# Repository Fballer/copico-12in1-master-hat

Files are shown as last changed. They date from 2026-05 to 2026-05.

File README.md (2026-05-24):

# Copico 12-in-1 Master Hat

The **Copico 12-in-1 Master Hat** is the ultimate expansion for the Tandy Color Computer. It emulates 12 legendary pieces of CoCo hardware using the high-performance Raspberry Pi RP2350 and an ESP32-C3 for wireless connectivity.

## 🚀 Emulated Hardware Features
1.  **Orchestra-90 CC**: 8-bit Stereo Audio.
2.  **Speech & Sound Pak**: PSG sound with automatic CoCo 3 pitch correction.
3.  **RS-232 Pak**: ACIA serial communication.
4.  **WordPak 2+**: MSX2+ (V9958) 80-column VGA graphics.
5.  **CoCoSDC**: High-speed MicroSD storage and disk emulation.
6.  **WiModem**: AT-command compatible wireless modem.
7.  **DriveWire 4**: Wireless virtual serial disk streaming.
8.  **FujiNet**: Cloud-based sector streaming and network tools.
9.  **Real-Time Clock**: DS3231-based system clock.
10. **SuperSprite FM+**: TMS9918 video + OPL2 FM synthesis sound.
11. **CoPico X-BIOS**: Software-based personality swapping via Native VDG menu.

## 📂 Repository Structure
*   `firmware/`: Source code for RP2350 (PIO-based bus trapping) and ESP32-C3.
*   `docs/`: Schematic, pin map, assembly guide, firmware roadmap.
*   `references/`: Technical specifications for the emulated hardware.

> **Developing locally:** Open [`copico.code-workspace`](copico.code-workspace) (includes `lwtools-4.21` + `copico-bonobo-main` siblings). See [Project ecosystem](docs/ecosystem.md).

## 🛠 Documentation
*   [Project ecosystem & workspace setup](docs/ecosystem.md)
*   [Hat schematic (verified wiring)](docs/schematic_copico10in1-fixed_2026-05-24.png)
*   [GPIO pin map](docs/pinmap.md)
*   [Hardware Build Guide](docs/build_guide.md)
*   [Firmware Architecture Plan](docs/firmware_plan.md)
*   [User Guide](docs/user_guide.md)

---
*Created with AntiGravity - May 2026*

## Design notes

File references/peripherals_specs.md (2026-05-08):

# Peripheral Technical Summary: Orchestra-90 and 6551 ACIA

## 1. Orchestra-90 (Sound Pak)
The Orch-90 is a dual 8-bit DAC system. It is extremely simple to emulate.
*   **$FF7A**: Left Channel DAC (Write 8-bit signed/unsigned byte).
*   **$FF7B**: Right Channel DAC (Write 8-bit signed/unsigned byte).
*   **Sampling**: There is no hardware timer. The CoCo CPU manually POKEs values to these ports to create waveforms. 
*   **RP2350 Implementation**: We trap the write to $FF7A/B and immediately push the value to the I2S DMA buffer.

---

## 2. 6551 ACIA (RS-232 Pak)
The ACIA is the standard serial controller for the CoCo. It is mapped to **$FF68-$FF6B**.

| Address | Register | Function |
| :--- | :--- | :--- |
| **$FF68** | **Data** | Read (Rx) / Write (Tx) serial data. |
| **$FF69** | **Status** | Read IRQ, Overrun, Framing Error, Tx/Rx buffer status. |
| **$FF6A** | **Command** | Control parity, interrupts, and DTR/RTS lines. |
| **$FF6B** | **Control** | Set Baud Rate (50 to 19200 bps), word length, and stop bits. |

### **Status Register Bits ($FF69 Read)**
*   **Bit 0 (IRQ)**: 1 = Interrupt has occurred.
*   **Bit 3 (Rx Full)**: 1 = Data received and ready to read from $FF68.
*   **Bit 4 (Tx Empty)**: 1 = Ready to accept new data for transmission.
*   **Bit 5 (DCD)**: Data Carrier Detect status.
*   **Bit 6 (DSR)**: Data Set Ready status.

### **Control Register Bits ($FF6B Write)**
*   **Bits 0-3**: Baud rate selection.
    *   `1110`: 9600 bps
    *   `1111`: 19200 bps
*   **Bits 5-6**: Word length (8, 7, 6, 5 bits).
*   **Bit 7**: Stop bits (1 or 2).

### **RP2350 Implementation**
The RP2350 will bridge these register writes to its internal **Hardware UART0** (connected to the MAX3232 module) or to the **ESP32-C3** for virtual WiModem functionality.

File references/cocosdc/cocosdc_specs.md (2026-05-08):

# CoCoSDC Technical Summary (Emulation Specifications)

## 1. Memory-Mapped Registers ($FF40 - $FF4B)
The CoCoSDC emulates a standard FDC at $FF40-$FF47 but uses $FF48-$FF4B for "Extended SDC Mode" operations.

| Address | Function (Extended Mode) |
| :--- | :--- |
| **$FF40** | **Control Register**: Write `$43` to activate Extended SDC Mode. |
| **$FF48** | **Command/Status**: Write commands (Read, Write, Mount); Read status bits. |
| **$FF49** | **LSN High**: Bits 16-23 of the 24-bit Logical Sector Number. |
| **$FF4A** | **LSN Mid / Data Port 1**: Bits 8-15 of LSN / 8-bit data transfer port. |
| **$FF4B** | **LSN Low / Data Port 2**: Bits 0-7 of LSN / 8-bit data transfer port. |

## 2. Status Register Bits ($FF48 Read)
*   **Bit 0 (BUSY)**: 1 = Controller is busy. Wait for 0 before sending a new command.
*   **Bit 1 (READY)**: 1 = Data is ready in the buffer (for Reads) or buffer is ready (for Writes).
*   **Bit 7 (ERROR)**: 1 = Operation failed.

## 3. Command Set ($FF48 Write)
*   **$80**: Read 256-byte sector from current LSN.
*   **$A0**: Write 256-byte sector to current LSN.
*   **$E0**: Mount Drive 0. Requires sending a 256-byte packet with the filename string.
*   **$E1**: Mount Drive 1.

## 4. Block Transfer Protocol
1.  Set the 24-bit LSN using $FF49, $FF4A, $FF4B.
2.  Issue command $80 or $A0.
3.  Wait for Bit 1 of $FF48 to go high.
4.  Transfer 256 bytes by alternating reads/writes between **$FF4A** and **$FF4B**. 
    *   *Note: In RP2350 emulation, we can detect the alternating access to handle the byte streaming from the internal SD buffer.*

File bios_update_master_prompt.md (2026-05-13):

# Master Task: Finalizing the CoPico X-BIOS (formerly Chameleon)

## 🎯 Objective
Update the 6809 assembly-based BIOS for the **Copico 12-in-1 Master Hat (RP2350 + ESP32-C3)**. The goal is to implement a robust "Setup Required" alert system for missing ROMs and a "Utility Page" for managing the new Flash ROM Bank architecture.

---

## 🏗️ System Architecture
- **Master Controller**: RP2350 (ARM Cortex-M33 @ 150MHz).
- **Coprocessor**: ESP32-C3 (Handles WiFi, SD Card, and Bluetooth).
- **Host**: Tandy Color Computer (CoCo) 1, 2, or 3.
- **Interconnect**:
    - **RP2350 <-> CoCo**: Parallel bus sniffer via PIO (Address: G32-G47, Data: G0-G7).
    - **RP2350 <-> ESP32**: High-speed SPI (G23/G24/G30/G31).
    - **Video**: 640x480 VGA (PIO/DMA driven).

---

## 💾 Flash ROM Bank Layout (256KB @ 0x3C0000)
The RP2350 uses its internal flash to store ROM images in 16KB slots.
- **Slot 0**: CoPico X-BIOS (Pre-loaded).
- **Slot 1**: SDC-DOS (Auto-installed from SD card).
- **Slot 2**: FujiNet BIOS (Pre-loaded/Downloadable).
- **Slot 3**: RS-232 Pak ROM (Pre-loaded).
- **Banks 0-7**: CoCoSDC Array (Bank 1 is pre-loaded with Disk BASIC 1.1).

---

## 🖥️ Shared Memory Interface ($C000 - $DFFF)
The BIOS runs in the CoCo's address space. The RP2350 serves data to the BIOS and monitors its state via specific memory addresses:
- **$C000 - $D7FF**: Main BIOS Binary (8KB).
- **$D800 - $D81F**: WiFi Status String (from ESP32).
- **$D820 - $D83F**: Firmware Version String.
- **$D840 - $D85F**: SD Card Status String.
- **$D880**: **FLASH_STATUS_BYTE** (Bit 0: 1=SDC-DOS Missing, 0=OK).
- **$FF70 - $FF73**: Hardware Config Registers (Audio, Video, Disk, Comm).
- **$FF74**: **MODE_SWITCH_CMD** (Write a mode ID here to trigger a hardware swap).

---

## ⚡ Hardware Pinout (Verified PCB Netlist)
- **PIN_BTN_DUAL (G19)**: Held at boot forces CoPico X-BIOS (Slot 0).
- **PIN_STATUS_LED (G17)**: System status.
- **VGA Sync**: H-Sync (G26), V-Sync (G27).
- **VGA RGB**: G18, G22, G28 (mapped via PIO).
- **I2S DAC**: BCK (G10), DIN (G11), LCK (G12).

---

## 🛠️ BIOS Requirements (6809 Assembly)
1. **Name Change**: Rename all UI labels and internal strings to **CoPico X-BIOS**.
2. **Startup Alert**: On boot, check `$D880`. If Bit 0 is set, display a large, detailed "SETUP REQUIRED" screen.
    - Message: "Please place COCOSDC.ROM in /ROMS/ folder on SD card and restart to install SDC-DOS."
3. **ROM Utility Page**:
    - Add a new menu page: `Flash ROM Management`.
    - Options: `Scan SD for ROMs`, `Clear Flash Bank`, `Re-install Defaults`.
4. **Hardware Pass-through**: Implement an option for `MODE_INTERNAL_ROM` which tri-states the Hat and lets the CoCo boot its internal ROMs.

---

## 📂 Current Progress
- C++ Flash Manager is complete and pushed to `phase8-rtc`.
- SPI timeouts and Jitter-free VGA are implemented.
- `switch_mode()` now handles 16KB flash loads and tri-state recovery.
- Project renamed to **CoPico X-BIOS**.

**Please begin by reviewing `firmware/master-hat-firmware/bios/xbios.asm` and proposing the UI update plan.**

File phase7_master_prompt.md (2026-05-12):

# Copico 12-in-1 Master Hat: Phase 7 (Wireless Suite) Master Prompt

## Role & Context
You are Antigravity, an expert embedded C++ AI coding assistant. We are building the firmware for the **Copico 12-in-1 Master Hat**, an expansion system for the vintage Tandy Color Computer (CoCo). 

We are starting **Phase 7: Wireless Suite**. To save tokens, we are beginning a fresh conversation. You must assimilate the following architecture, constraints, and progress to continue seamlessly.

## System Architecture
The system utilizes a dual-processor architecture:
1.  **Host Processor**: Raspberry Pi RP2350.
    *   **Core 1**: Runs a hyper-critical PIO bus sniffer (`coco_bus.pio`). It listens to the CoCo's 6809 CPU and must respond within **<500ns**. *Rule: Never introduce blocking delays, Mutexes, or heavy computation on Core 1.*
    *   **Core 0**: Handles the main loop, peripheral emulation (`tick()` functions), and I2S/VGA DMA management.
2.  **Network Coprocessor**: ESP32-C3. 
    *   Dedicated to handling TCP/IP, WiFi, Telnet, and FAT32 SD Card operations.

### The Interconnect (SPI)
The RP2350 and ESP32-C3 communicate exclusively over SPI. 
*   **RP2350 Pins**: `MISO` (23), `MOSI` (24), `CS` (26), `SCK` (28).
*   **Protocol**: Defined in `lib/shared/spi_protocol.h`. It relies on a fixed 264-byte packet (`SpiMasterPacket` / `SpiSlavePacket`) padded with a sync byte (0xAA) and a checksum.
*   **Current State**: We currently have two classes trying to use SPI: `Esp32Bridge` (synchronous, blocking polling used for SD card reads) and `SpiStream` (asynchronous, non-blocking tick-based stream meant for WiModem serial). *They currently share the same pins and need unification/careful management.*

## Current Project State (Phases 1-6 Complete)
*   **Chameleon BIOS**: We have completely written a 6809 assembly BIOS (`bios/chameleon.asm`) that lives in the RP2350 and gets injected into the CoCo's ROM space at `$C000-$DFFF`. It provides a native 32x16 UI to dynamically swap emulator modes (e.g., `MODE_WIMODEM`, `MODE_COCOSDC`, `MODE_ORCH90`).
*   **Shared BIOS Memory**: The BIOS reads real-time status strings from the RP2350 at specific memory addresses:
    *   `$C800`: WiFi Status String
    *   `$C820`: ESP32 Firmware Version String
    *   `$C840`: SD Card Status String
*   **Emulators Built**: We have functioning classes for `Acia6551` (RS-232), `Pic7040`/`Ay8913`/`Spo256` (Speech/Sound), `V9958` (VGA), and `Cocosdc` (SD floppy).

## Phase 7 Goals
The objective of Phase 7 is to bring the ESP32-C3 online and implement the **WiModem** (an RS-232 to Telnet bridge for BBSing).

### 1. The ESP32 Firmware (New Project)
You will need to help scaffold a brand new PlatformIO project for the ESP32-C3.
*   **Project Location**: Create the new project in `firmware/esp32-coprocessor`.
*   **Environment**: Use `board = esp32-c3-devkitm-1` (or equivalent C3 board) and `framework = arduino`.
*   **Reference**: We are NOT building the modem from scratch. You must reference the local project at `/Users/macbook/Documents/PlatformIO/Projects/New_Porta_Serial_esp32c3`. This contains a working implementation of `Zimodem` (an industry-standard AT command parser) previously built for the CoCo.
*   **Adaptation**: We must strip out the hardware UART dependencies in the `Zimodem` reference and pipe its I/O through our SPI Slave interface (`ESP32SPISlave` library) using the fixed 264-byte packets.

### 2. The RP2350 Firmware (Existing Project)
*   **Existing ACIA Work**: We have already completed the `Acia6551` class (during Phase 3). While it is pending final hardware verification, it supports both Legacy and Turbo modes (up to 115200 baud) and is designed to accept ANY Arduino `Stream` via dependency injection. **Do NOT rebuild or modify `acia6551.cpp` for no reason**.
*   **Bridging**: In `main.cpp`, the physical RS-232 Pak uses `Acia6551 acia(&rs232_serial);`. For the WiModem, we have already wired up `Acia6551 wimodem(&spi_wimodem_stream);`. When `current_mode == MODE_WIMODEM`, Core 1 successfully routes `$FF68-$FF6B` register access to this `wimodem` object.
*   **SpiStream**: Because `wimodem` takes the `SpiStream` pointer, your only task on the RP2350 side is to finalize `spi_stream.cpp`. You must ensure that bytes written to the ACIA are pushed into the SPI TX ring buffer, and then flushed to the ESP32 via our 264-byte SPI packets during Core 0's 5ms `tick()` cycle.

## Your Immediate Instructions
1. Acknowledge this context and confirm your understanding of the architecture.
2. Draft a step-by-step Execution Plan for Phase 7 based on this prompt. 
3. Stop and wait for my approval before modifying any files or executing terminal commands.

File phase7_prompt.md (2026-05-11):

# Phase 7: Wireless Suite (ESP32-C3) - AI Prompt

**Role:** You are Antigravity, an expert embedded C++ AI coding assistant. We are building the firmware for the Copico 12-in-1 Master Hat, an expansion system for the Tandy Color Computer (CoCo) that uses an RP2350 (Host) and an ESP32-C3 (Network Coprocessor).

**Objective:** Begin Phase 7 (Wireless Suite). The goal is to integrate the ESP32-C3 over SPI to provide the CoCo with WiFi, a WiModem (RS-232 to Telnet bridge), DriveWire/FujiNet network disk streaming, and Cloud CoCoSDC capabilities.

### System Context & Constraints (Phases 1-6 Completed)
You are building on top of a highly integrated, stable codebase. You must ensure new code does not break existing functionality.
1.  **Architecture**: Dual-Core RP2350. Core 1 runs a time-critical PIO bus sniffer (`coco_bus.pio`) that responds to the 6809 CPU in <500ns. Core 0 handles high-level emulation loops (`tick()` functions).
2.  **Current Modes**: We have successfully implemented `MODE_ORCH90`, `MODE_SPEECH_SOUND`, `MODE_RS232_PAK_LEGACY`/`TURBO`, `MODE_WORDPAK2` (VGA), and `MODE_COCOSDC` (SD Card FAT32).
3.  **Hardware Resources (CRITICAL)**:
    *   **PIO0**: 2 SMs used by the Bus Sniffer.
    *   **PIO1**: 3 SMs used by the VGA Driver.
    *   **DMA**: VGA and I2S audio use active DMA channels.
    *   *Do NOT reallocate these resources or introduce blocking delays in Core 1.*
4.  **ESP32-C3 Hardware Mapping**:
    *   The ESP32 communicates with the RP2350 via SPI on these RP2350 pins: `MISO` (G23), `MOSI` (G24), `CS` (G26), `SCK` (G28).

### Phase 7 Requirements & Strategy
1.  **Do NOT Build From Scratch**: Leverage existing open-source projects to save time and ensure stability.
    *   **WiModem (7B)**: Reference `Zimodem` (boisy/Zimodem) or `GuruModem` for handling AT commands and Telnet bridging.
        *   **CRITICAL REFERENCE**: Use the local project [New_Porta_Serial_esp32c3](file:///Users/macbook/Documents/PlatformIO/Projects/New_Porta_Serial_esp32c3) as a primary guide. It contains a working WiModem setup previously built for the CoCo using the same ESP32-C3 processor.
    *   **Network Drives (7C/7D)**: Reference the `FujiNet` firmware stack (FujiNetWIFI) for SPI-to-Network bridging, or `pyDriveWire` specs for the DriveWire protocol.
2.  **Dual-Firmware Architecture**: We will need to write/adapt firmware for **both** the RP2350 (to marshal data between the CoCo bus and SPI) and the ESP32-C3 (to handle the TCP/IP stack and AT commands).
3.  **Integration**: The RP2350 logic must fit into our existing "Chameleon" architecture. For example, when `current_mode = MODE_WIMODEM`, Core 1 should trap the ACIA 6551 registers (like in Phase 3) but route the data to the ESP32 via SPI instead of a local hardware UART.

### Your First Task:
1.  Analyze this prompt and the current state of the workspace (specifically `main.cpp` and `docs/firmware_plan.md`).
2.  Do NOT write C++ code yet. 
3.  Draft a detailed `implementation_plan.md` for Phase 7. 
    *   Outline the SPI communication protocol we will use between the RP2350 and ESP32.
    *   Specify which open-source libraries we will pull in for the ESP32 firmware.
    *   Detail how we will bridge the existing `Acia6551` class to the new WiFi modem.
4.  Stop and wait for my approval before modifying source files.

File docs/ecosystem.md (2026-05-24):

# CoPico project ecosystem

This repo (`copico-12in1-master-hat`) is the **shipping firmware** for the PortaCoco 10-in-1 Centipede 32z hat. It sits inside a larger folder on disk that you should open as one workspace when developing.

## Recommended Cursor / IDE workspace

**Option A (best):** Open `copico.code-workspace` in this repo — it includes this firmware, `lwtools-4.21`, and `copico-bonobo-main` as multi-root folders. Bonobo KiCad/Gerbers are excluded from search/index via `copico-bonobo-main/.cursorignore` and workspace `search.exclude` (keeps `centipede-watcher/`, `references/`, and `.md` files).

**Option B:** Open the parent folder:

```
/Users/macbook/Documents/PlatformIO/Projects/copico/
```

That gives agents and search access to build tools and reference material without copying them into git.

## Sibling folders (under `copico/`)

| Path | Purpose |
|---|---|
| **`copico-12in1-master-hat/`** (this repo) | RP2350 + ESP32 firmware, docs, `references/` |
| **`lwtools-4.21/`** | 6809 assembler (`lwasm`) for CoPico X-BIOS — used by `firmware/master-hat-firmware/bios/build_bios.py` |
| **`copico-bonobo-main/`** | Centipede 32z/32d KiCad, `centipede-watcher` bus-sniffer experiments, extra `hat-fuji-40c/references/` |
| **`hardware/`** | Production Gerbers, schematic PDFs, PCB archives (not source of truth for day-to-day wiring) |

## Authoritative hardware docs (this repo)

| Doc | Use |
|-----|-----|
| [schematic_copico10in1-fixed_2026-05-24.png](schematic_copico10in1-fixed_2026-05-24.png) | **Wiring you built** — PortaCoco 10-in-1 hat (rev 2.12) |
| [pinmap.md](pinmap.md) | GPIO ↔ net names ↔ firmware `#define`s |
| [build_guide.md](build_guide.md) | Assembly BOM and J3/J4 steps (verified section only) |

Ignore `hardware/` in this repo (excluded via `.cursorignore`) — old FujiNet-era KiCad, not the Centipede hat you assembled. Use `docs/schematic_copico10in1-fixed_2026-05-24.png` instead.

## Build commands

```bash
# RP2350 (default)
cd firmware/master-hat-firmware && pio run -e rp2350

# ESP32 coprocessor (from same project)
pio run -e esp32c3_coprocessor

# CoPico X-BIOS ROM (needs lwasm — see lwtools-4.21 sibling)
cd firmware/master-hat-firmware/bios && python3 build_bios.py
```

## Centipede base board (CoCo bus)

The hat schematic covers J3/J4 peripherals. The **6809 bus** pins are on the Centipede 32z itself:

| CoCo signal | RP2350 GPIO | Firmware |
|---|---|---|
| D0–D7 | 0–7 | `coco_bus.pio` |
| A0–A15 | 32–47 | `coco_bus.pio` |
| R/W | 20 | `PIN_RW`, PIO jmp pin |
| E-clock | 21 | `PIN_E_CLOCK` |

See `copico-bonobo-main/v3.1-centipede/README.md` for the full Centipede pin table (Q, NMI, RESET, etc.).

## Git

Only `copico-12in1-master-hat` is a git repository. Siblings are local support files — do not expect them on GitHub clones unless you copy `lwtools-4.21` yourself or install `lwasm` on PATH.

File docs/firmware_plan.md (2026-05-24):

# Copico 12-in-1 Master Hat: Firmware Architecture & Implementation Plan
**Date: May 2026 — Updated with verified PCB netlist (Hat-Fuji-40C v1)**

This document details the software architecture and development roadmap for the **12-in-1 Master Hat**. It leverages the RP2350 dual-core processor to emulate an entire suite of CoCo expansions.

> [!IMPORTANT]
> This plan assumes the hardware is built according to the [Hardware Assembly Guide](build_guide.md) and [pin map](pinmap.md) (see [schematic](schematic_copico10in1-fixed_2026-05-24.png)).

## 1. System Philosophy: The "CoPico X-BIOS" Expansion
The RP2350 acts as a real-time bridge between the CoCo's 6809 bus and modern peripherals. By dynamically swapping PIO state machines and memory maps, a single physical board becomes 12 different classic cartridges.

> [!IMPORTANT]
> **LOCAL SPECIFICATIONS FIRST**: The technical "guts" (registers, ports, and protocols) for these modules have been saved directly to this project. **Reference these local files first** during the firmware build to ensure we stay offline and fast.

| Emulation Mode | Core Hardware | Technical Reference / Repository |
| :--- | :--- | :--- |
| **Orchestra-90** | 8-bit Mono DAC | [Archive: Orch-90 Manual](https://colorcomputerarchive.com/repo/Documents/Manuals/Hardware/Orchestra-90%20(Tandy).pdf) \| **[LOCAL: Peripherals Specs](../references/peripherals_specs.md)** |
| **Speech & Sound** | AY-3-8910 (PSG) | [GitHub: AY-3-8910 Emulation](https://github.com/mamedev/mame/blob/master/src/devices/sound/ay8910.cpp) \| [GitHub: LibAYemu](https://github.com/vsergeev/libayemu) |
| **RS-232 Pak** | ACIA 6551 | [Reference: 6551 Datasheet](https://www.westerndesigncenter.com/wdc/documentation/w65c51n.pdf) \| **[LOCAL: Peripherals Specs](../references/peripherals_specs.md)** |
| **WordPak 2+** | Yamaha V9958 | [Source: CoCoLoCo WordPak-2](https://sites.google.com/site/tandycocoloco/wordpak-2) \| **[LOCAL: V9958 Specs](../references/wordpak2/v9958_specs.md)** |
| **CoCoSDC** | Custom FDC | [Blog: CoCoSDC Official](http://cocosdc.blogspot.com/) \| **[LOCAL: CoCoSDC Specs](../references/cocosdc/cocosdc_specs.md)** |
| **FujiNet** | ESP32 Networking | [GitHub: FujiNet PlatformIO](https://github.com/FujiNetWIFI/fujinet-platformio) \| [GitHub: fujinet-firmware](https://github.com/FujiNetWIFI/fujinet-firmware) |
| **DriveWire 4** | Virtual Serial Disk | [Source: DriveWire 4](http://www.drivewire4.com/) \| [GitHub: pyDriveWire](https://github.com/n64764/pyDriveWire) |
| **WiModem** | AT Command Modem | [Reference: Zimodem Firmware](https://github.com/boisy/Zimodem) \| [GitHub: GuruModem](https://github.com/pizet/GuruModem) |
| **Real-Time Clock** | MSM5832 Emulation | [Library: DS3231 I2C](https://github.com/adafruit/Adafruit_DS3231) \| [GitHub: CoCo RTC Driver](https://github.com/boisy/NitrOS-9/blob/master/sys/modules/rtc3231.as) |
| **SuperSprite FM+** | TMS9918 + OPL2 | [Reference: TMS9918 Datasheet](https://www.msxarchive.nl/pub/msx/mirrors/hansa.xs4all.nl/tms9918.pdf) \| [GitHub: OPL2 Emulator](https://github.com/D-S-X/OPL2-Emulation) |
| **CoPico X-BIOS** | Injected 6809 Code | [Source: FujiNet Config Application](https://github.com/FujiNetWIFI/fujinet-config) \| [GitHub: Mega-Cart](https://github.com/sublogic/MegaCart) |

---

## 3. Development Roadmap & Success Probability

We will develop each module in isolation, hardcoding the RP2350 for testing before integrating them into the master Boot Menu.

### Phase 1: Orchestra-90 Emulation (Success: 95%)
*   Trap `$FF7A/B` and push to I2S DAC. Simple bus-sniffing "quick win."

### Phase 2: Speech and Sound Pak (Success: 85%)
*   Real-time synthesis of PSG waveforms in the RP2350 CPU core.
*   **CoCo 3 / 6309 / GIME-X Auto-Correction**: Detect host E-Clock frequency in real-time (0.89MHz to 3MHz+). Normalizes PSG pitch and ensures bus-trapping logic remains stable during high-speed operation.

### Phase 3: RS-232 Pak (Success: 90%)
*   Emulate ACIA registers and route to physical MAX3232 pins.

### Phase 4: WordPak 2+ (V9958 VGA) (Success: 75%)
*   **The "Boss Fight"**: Emulate MSX2+ graphics and output 3-bit RGB VGA. Requires intense PIO optimization. Master this first to provide the video foundation for the SuperSprite.

### Phase 5: The Native Boot Menu (Success: 85%)
*   Inject 6809 assembly into CoCo RAM to display a selection menu on the native screen.

### Phase 6: CoCoSDC (Local Storage) (Success: 80%)
*   Implement FAT32 support and precise floppy controller timing.

### Phase 7: Wireless Suite (ESP32-C3)
*   **7A. WiFi Connection** (95%)
*   **7B. Wireless WiModem** (90%): Bridge RS-232 to Telnet via ESP32.
*   **7C. FujiNet / DriveWire** (80%): Stream sectors over the local network.
*   **7D. Cloud CoCoSDC** (75%): Fetch `.DSK` files directly from the Color Computer Archive.

### Phase 8: SuperSprite FM+ (Success: 70%)
*   **Advanced Feature**: Leverage the V9958 VGA core from Phase 4 and add software FM synthesis (OPL2 emulation). This turns the CoCo into an FM-synth music machine.

---

## 4. Boot Menu & ROM Management
*   **Native VDG Menu**: The primary menu runs on the CoCo's original green/black screen.
*   **BIOS Shared Memory**: The RP2350 exposes a shared memory block starting at `$D800` for the 6809 to read real-time status strings dynamically injected by the ESP32 and RP2350:
    *   `$D800`: WiFi Status (max 32 bytes, null-terminated)
    *   `$D820`: ESP32 Firmware Version (max 32 bytes, null-terminated)
    *   `$D840`: SD Card Status (max 32 bytes, null-terminated)
    *   `$D860`: Time Zone Setting (max 32 bytes, null-terminated)

> [!NOTE]
> Status buffers were relocated from `$C800` to `$D800` (Phase 8) to prevent conflicts with the BIOS ROM code space (`$C000-$DFFF`).

*   **Hardware Registers**:
    *   `$FF50-$FF51`: Emulated MSM5832 RTC interface (compatible with Disto 4-N-1 and NitrOS-9).
    *   `$FF70`: Boot Menu Audio selection register.
    *   `$FF71`: Boot Menu Video selection register.
    *   `$FF72`: Boot Menu Disk selection register.
    *   `$FF73`: Boot Menu Comm selection register.
    *   `$FF75`: Time Zone index register (Write 0-17 to select timezone; ESP32 applies POSIX TZ string).
    *   `$FF7F`: Mode-switch register (Write EmulatorMode value to switch; Write `$55` from Boot Menu to save+switch).

*   **RP2350 ↔ ESP32 SPI Link (Verified PCB Netlist)**:
    *   **CS** : RP2350 **G23** ↔ ESP32 **GPIO4** (J4 Pin 7)
    *   **MISO**: RP2350 **G24** ↔ ESP32 **GPIO0** (J4 Pin 9)
    *   **SCK** : RP2350 **G30** ↔ ESP32 **GPIO3** (J4 Pin 15)
    *   **MOSI**: RP2350 **G31** ↔ ESP32 **GPIO1** (J4 Pin 16)
*   **Personality Swapping**: Selecting a menu item triggers a "hot-swap" of the RP2350's memory mapping.

### ROM Management Strategy (16KB Flash Bank Architecture)
The CoPico X-BIOS leverages a robust 256KB flash bank (12 slots of 16KB) for instant-on performance and hardware-accurate bank switching:

1.  **Slot 0: CoPico X-BIOS**: (Embedded). The system's primary control menu.
2.  **Slot 1: SDC-DOS**: (Auto-installed). Required for CoCoSDC disk emulation. Installed from SD card on first boot to maintain legal compliance.
3.  **Slot 2: FujiNet BIOS**: (Embedded). Networking ROM for the ESP32 bridge.
4.  **Slot 3: RS-232 Pak ROM**: (Embedded). Deluxe RS-232 ROM for terminal communication.
5.  **Slots 4-11: CoCoSDC Banks**: Emulates the 8-bank hardware array. Bank 0 (Slot 4) defaults to SDC-DOS; Bank 1 (Slot 5) defaults to Disk BASIC 1.1.

*   **Recovery Mode**: Powering on while holding **G19** (Dual Button) forces an immediate bypass to the CoPico X-BIOS (Slot 0), allowing recovery from a soft-bricked state.
*   **Bank Switching**: Responds to `RUN @n` commands via the PIO bus sniffer, mirroring the real CoCoSDC hardware behavior.

### Bus Timing: Hybrid Fast-Map I/O Dispatch

> [!IMPORTANT]
> The CoCo bus at **2.86 MHz** (GIME-X + 6309 turbo) gives only **175 ns** to respond to a read. The original firmware used a C++ `if/else` chain that consumed ~40 ns in branch comparisons alone. Combined with slow `gpio_set_dir_out_masked()` calls, worst-case latency was ~500 ns — a guaranteed failure at turbo speeds.

**Solution (Phase 8 Fortification):**

1.  **PIO Read-Response SM** (`coco_bus_read`): A third PIO state machine on PIO0 handles the entire GPIO turnaround (set output → drive data → wait E-clock fall → tri-state) in hardware. This replaced ~150 ns of C++ MMIO calls with a single 7 ns FIFO write (`BUS_RESPOND()` macro).

2.  **Hybrid Fast-Map**: The `if/else` dispatch chain was replaced with:
    *   **ROM Shadow** (`$C000-$DFFF`): A single function pointer (`rom_read_handler`). One comparison + one indirect call = ~20 ns.
    *   **I/O Space** (`$FF00-$FFFF`): A 256-entry function pointer table (`io_read_table[]` / `io_write_table[]`), indexed by `addr & 0xFF`. One array access + null check + indirect call = ~7 ns.
    *   Tables are rebuilt on every mode switch via `rebuild_io_tables()`.

| CoCo Speed | Budget | Estimated Latency | Margin |
| :--- | :--- | :--- | :--- |
| 1.0 MHz (Stock) | 500 ns | ~120 ns | ✅ 380 ns |
| 1.79 MHz (Turbo) | 279 ns | ~120 ns | ✅ 159 ns |
| 2.86 MHz (GIME-X) | 175 ns | ~120 ns | ✅ **55 ns** |

*   **Source files**: `io_dispatch.h`, `io_dispatch.cpp`, `coco_bus.pio` (`coco_bus_read` program).
*   **Memory cost**: 256 × 4 bytes × 2 tables = **2 KB RAM** (negligible on RP2350's 520 KB).

### VGA Jitter Elimination (DMA Interrupt-Driven Double Buffer)

> [!NOTE]
> The VGA signal is generated entirely by PIO1 (3 state machines: HSYNC, VSYNC, RGB) and fed by a DMA chain. The CPU is **never** in the VGA timing path.

**Problem**: The original `tick()` function used a blocking `while()` loop that spun until the DMA finished reading a scanline buffer. If the CPU was busy (audio synthesis, bus handling), the loop stalled, causing visible jitter.

**Solution**: A DMA completion interrupt (`DMA_IRQ_0`) fires when each scanline transfer finishes. The ISR:
1.  Atomically swaps the active buffer index (0 ↔ 1)
2.  Points the DMA at the new buffer
3.  Increments a `_scanlines_completed` counter

`tick()` checks the counter. If > 0, it renders the next scanline into the inactive buffer. If `tick()` falls behind (CPU busy), the DMA simply replays the last buffer — a graceful degradation (repeated scanline) instead of signal corruption.

*   **Source files**: `vga_driver.h`, `vga_driver.cpp`, `vga_pio.pio`
*   **ISR**: `VgaDriver::on_dma_complete()` (static, registered on `DMA_IRQ_0`)
*   **CPU impact**: Zero. VGA signal is 100% hardware-driven.

---

### Multi-Pak Interface (MPI) Compatibility
While the 10-in-1 Hat cannot connect directly to a physical floppy drive, it **can** operate inside a Tandy Multi-Pak Interface alongside a real physical Disk Controller. 
*   **Hardware Handshake**: The Hat relies on the `CTS*` (Cartridge Select) signal. When in an MPI, the MPI hardware only sends the `CTS*` signal to the currently selected slot. 
*   **Result**: The Copico will remain completely "silent" on the bus until the CoCo switches to its specific MPI slot, allowing it to perfectly co-exist with real floppy controllers or other physical cartridges without bus conflicts.

*   **Physical Override**: The SPDT switch (G20) allows forcing a "Safe Mode" boot to the menu if a firmware setting gets stuck.

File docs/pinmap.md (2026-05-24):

# GPIO pin map — verified against schematic & firmware

Source: `docs/schematic_copico10in1-fixed_2026-05-24.png` (PortaCoco 10-in-1 Centipede 32z Hat, rev 2.12) and firmware as of May 2026.

## J3 — RP2350 (2×10)

| J3 pin | Net | GPIO | Firmware |
|---|-----|---|---|
| 1 | VGA_GREEN_G8 | G8 | `vga_driver.cpp` `PIN_GREEN` |
| 5 | Sound_BCK_G10 | G10 | `main.cpp` `I2S_BCK` |
| 7 | Sound_DIN_G11 | G11 | `I2S_DIN` |
| 9 | Sound_LCK_G12 | G12 | `I2S_LCK` |
| 11 | TTL_TX_G13 | G13 | `SerialPIO` TX |
| 12 | VGA_RED_G14 | G14 | `PIN_RED` |
| 13 | TTL_RX_G15 | G15 | `SerialPIO` RX |
| 14 | VGA_VSync_G16 | G16 | `PIN_VSYNC` |
| 15 | SDC_LED_G17 | G17 | `PIN_STATUS_LED` |
| 16 | VGA_HSync_G18 | G18 | `PIN_HSYNC` |
| 17 | SDC_Button_G19 | G19 | `PIN_BTN_DUAL` |
| 18 | RESET | — | Hardware reset pad |

## J4 — RP2350 ↔ ESP32-C3 SPI

| J4 pin | Net | RP2350 | ESP32-C3 | Firmware |
|---|-----|---|---|---|
| 7 | ESP_C3_CS_G23 | G23 | GPIO4 | `esp32_bridge.cpp`, `spi_stream.cpp` |
| 9 | ESP_C3_MISO_G24 | G24 | GPIO0 | |
| 15 | ESP_C3_SCK_G30 | G30 | GPIO3 | |
| 16 | ESP_C3_MOSI_G31 | G31 | GPIO1 | |
| 10 | SND | — | — | Audio coupling (C1), not a GPIO |

## ESP32-C3 — MicroSD (CoCoSDC, not on RP2350)

| Net | ESP32 GPIO | Firmware (`main_esp32.cpp`) |
|-----|---|---|
| SDC_MOSI | 5 | `SD_MOSI` |
| SDC_MISO | 6 | `SD_MISO` |
| SDC_SCK | 7 | `SD_SCK` |
| SDC_CS | 10 | `SD_CS` |

## CoCo cartridge bus (Centipede 32z — not on hat schematic)

| Signal | GPIO | Firmware |
|---|---|---|
| D0–D7 | 0–7 | `coco_bus.pio` |
| A0–A15 | 32–47 | `coco_bus.pio` |
| R/W | 20 | `PIN_RW` |
| E-clock | 21 | `PIN_E_CLOCK` |

## Modules on schematic

| Block | Interface |
|---|---|
| PCM5102A | I2S G10–G12 → RCA (R7/R8, trimpot R9) |
| HW-044 | TTL G13/G15 → DB9 |
| VGA HD15 | RGB + sync G8, G9, G14, G16, G18 |
| ESP32-C3 Super Mini | SPI to J4; SD on GPIO 5–7, 10 |
| CoCoSDC LED / button | G17, G19 |

RTC is **software-emulated** on the RP2350 (`rtc.cpp`), synced from ESP32 NTP over SPI — no DS3231 on this schematic.

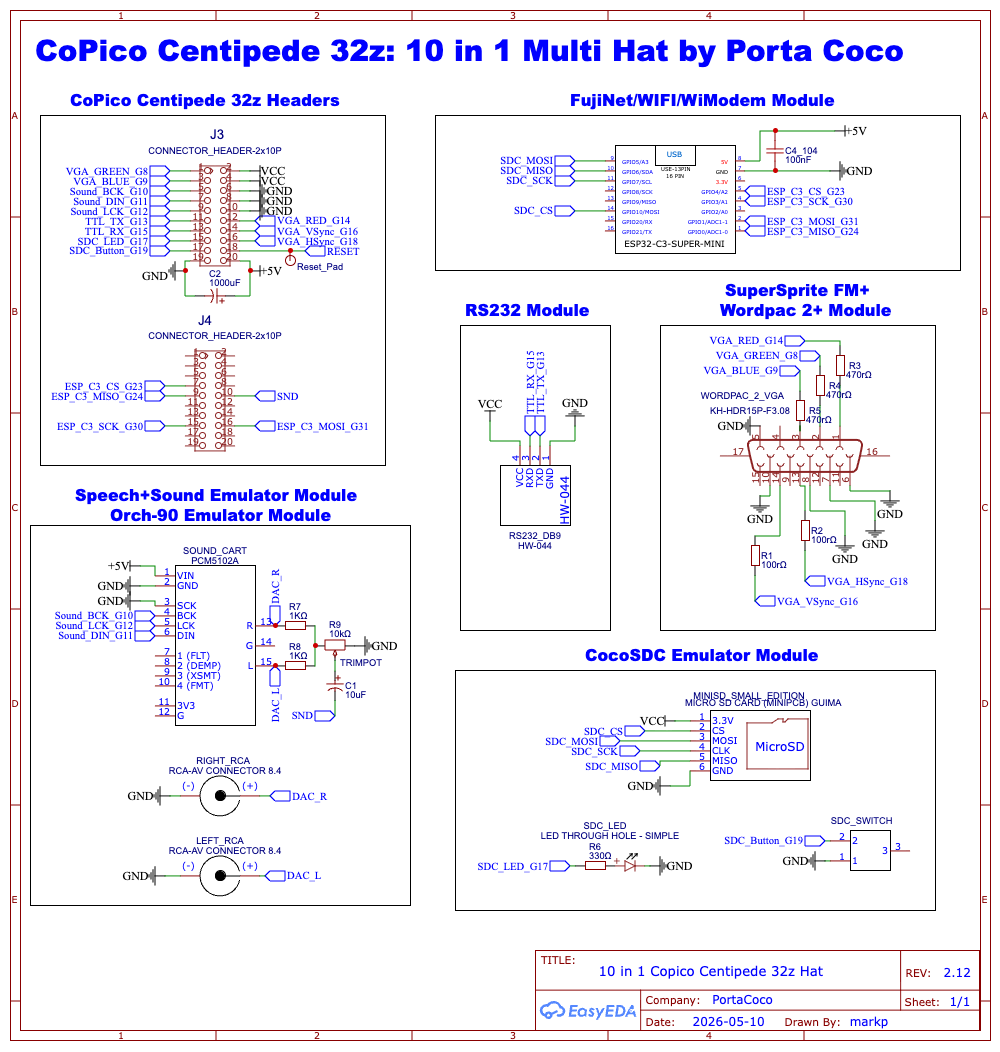
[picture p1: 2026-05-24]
docs/schematic_copico10in1-fixed_2026-05-24.png

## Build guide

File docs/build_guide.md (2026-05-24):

# Copico 12-in-1 Master Hat: Hardware Assembly Guide
**Date: May 2026 — Verified against PCB Netlist (Hat-Fuji-40C v1)**

This guide provides the complete Bill of Materials (BOM) and wiring instructions for the **12-in-1 Master Hat** built on the **Centipede 32z** board.

> [!IMPORTANT]
> This hardware is designed to work in tandem with the [Firmware Architecture Plan](./firmware_plan.md).
> Ensure all power is disconnected from the Centipede and CoCo before soldering.

> [!CAUTION]
> All GPIO assignments are **verified against** [schematic_copico10in1-fixed_2026-05-24.png](schematic_copico10in1-fixed_2026-05-24.png) (PortaCoco 10-in-1 hat, rev 2.12). See [pinmap.md](pinmap.md). An older duplicate section with wrong SD/SPI pins was removed from this file.

## Bill of Materials (BOM)

### Core Components
*   **[ ] 1x Centipede 32z Board**
*   **[ ] 2x 20-pin Female Headers (2x10, 2.54mm pitch)** (J3 and J4 slots)
*   **[ ] 1x MicroSD Card Module** (Mini PCB — GUIMA edition as per BOM)
*   **[ ] 1x PCM5102A I2S DAC Module** (Orchestra-90 / Speech+Sound output)
*   **[ ] 1x HW-044 TTL-to-RS232 Module** (MAX3232-based, DB9 connector)
*   **[ ] 1x ESP32-C3 Super Mini Module** (FujiNet / WiModem / CoCoSDC coprocessor)

### Connectors & Switches
*   **[ ] 1x HD15 Female VGA Connector** (KH-HDR15P-F3.08 footprint)
*   **[ ] 2x RCA Jacks** (Stereo audio out: LEFT_RCA, RIGHT_RCA)
*   **[ ] 1x Side-Mounted Push Button (4.5x4.5, 3-pin)** (CoCoSDC Disk Swap)
*   **[ ] 1x 5mm LED** (CoCoSDC Activity Indicator)

### Passive Components
*   **[ ] 2x 100Ω Resistors** (R1, R2 — VGA Sync lines: HSync, VSync)
*   **[ ] 3x 470Ω Resistors** (R3, R4, R5 — VGA Red, Green, Blue)
*   **[ ] 1x 330Ω Resistor** (R6 — Status LED current limiter)
*   **[ ] 2x 1kΩ Resistors** (R7, R8 — Audio DAC output mixing)
*   **[ ] 1x 10kΩ Trimpot** (R9 — Volume Control)
*   **[ ] 1x 10µF Electrolytic Capacitor** (C1 — Audio coupling/SND line)
*   **[ ] 1x 1000µF Electrolytic Capacitor** (C2 — 5V rail power stabilizer)
*   **[ ] 1x 100nF Ceramic Capacitor** (C4_104 — ESP32 3.3V noise filter)

---

## Verified GPIO Map (RP2350 Centipede 32z)

### J3 Header (2x10, 2.54mm)
| J3 Pin | Net Name | GPIO | Function |
| :--- | :--- | :--- | :--- |
| 1 | VGA_GREEN_G8 | **G8** | WordPak VGA Green -> R4 (470Ω) -> VGA Pin 2 |
| 2 | VCC | 3.3V | Power Rail |
| 3 | VGA_BLUE_G9 | **G9** | WordPak VGA Blue -> R5 (470Ω) -> VGA Pin 3 |
| 4 | VCC | 3.3V | Power Rail |
| 5 | Sound_BCK_G10 | **G10** | I2S DAC Bit Clock |
| 6 | GND | GND | Ground |
| 7 | Sound_DIN_G11 | **G11** | I2S DAC Data In |
| 8 | GND | GND | Ground |
| 9 | Sound_LCK_G12 | **G12** | I2S DAC LR Clock |
| 10 | GND | GND | Ground |
| 11 | TTL_TX_G13 | **G13** | RS-232 UART TX |
| 12 | VGA_RED_G14 | **G14** | WordPak VGA Red -> R3 (470Ω) -> VGA Pin 1 |
| 13 | TTL_RX_G15 | **G15** | RS-232 UART RX |
| 14 | VGA_VSync_G16 | **G16** | WordPak VGA VSync -> R1 (100Ω) -> VGA Pin 14 |
| 15 | SDC_LED_G17 | **G17** | Status LED -> R6 (330Ω) -> LED |
| 16 | VGA_HSync_G18 | **G18** | WordPak VGA HSync -> R2 (100Ω) -> VGA Pin 13 |
| 17 | SDC_Button_G19 | **G19** | SDC Swap Button (active LOW) |
| 18 | RESET | RESET | Hardware Reset Pad |
| 19 | GND | GND | Ground |
| 20 | +5V | 5V | Power Rail (also C2 1000µF) |

### J4 Header (2x10, 2.54mm) — ESP32 SPI Coprocessor Link
| J4 Pin | Net Name | GPIO | Function |
| :--- | :--- | :--- | :--- |
| 7 | ESP_C3_CS_G23 | **G23** | SPI CS -> ESP32 GPIO4 |
| 9 | ESP_C3_MISO_G24 | **G24** | SPI MISO <- ESP32 GPIO0 |
| 10 | SND | SND | Audio SND line (C1 coupling cap) |
| 15 | ESP_C3_SCK_G30 | **G30** | SPI SCK -> ESP32 GPIO3 |
| 16 | ESP_C3_MOSI_G31 | **G31** | SPI MOSI -> ESP32 GPIO1 |

### ESP32-C3 Super Mini GPIO Map
| ESP32 Pin | Net Name | Function |
| :--- | :--- | :--- |
| GPIO0 / ADC1-0 | ESP_C3_MISO_G24 | SPI MISO <- RP2350 G24 |
| GPIO1 / ADC1-1 | ESP_C3_MOSI_G31 | SPI MOSI -> RP2350 G31 |
| GPIO2 / A0 | (Spare) | — |
| GPIO3 / A1 | ESP_C3_SCK_G30 | SPI SCK <- RP2350 G30 |
| GPIO4 / A2 | ESP_C3_CS_G23 | SPI CS <- RP2350 G23 |
| GPIO5 / A3 | SDC_MOSI | SD Card MOSI |
| GPIO6 / SDA | SDC_MISO | SD Card MISO |
| GPIO7 / SCL | SDC_SCK | SD Card CLK |
| GPIO8 / SCK | (Internal pull-up boot) | |
| GPIO9 / MISO | (Boot mode / spare) | |
| GPIO10 / MOSI | SDC_CS | SD Card Chip Select |
| GPIO20 / RX | (Internal UART RX) | |
| GPIO21 / TX | (Internal UART TX) | |
| 5V pin (8) | +5V | Power from Centipede |
| GND pin (7) | GND | Ground |
| 3.3V pin (6) | +3.3V (via C4_104) | Clean 3.3V for SD Card |

---

## Step-by-Step Assembly

### Phase 1: Header Installation & Power
1.  Solder 2x10 female headers into **J3** and **J4**.
2.  Solder **C2 (1000µF)** across **J3 Pin 20 (+5V)** and **J3 Pin 10 (GND)** for WiFi power stability.
3.  Solder **C4_104 (100nF)** across the ESP32 module's **5V** and **GND** pins.

### Phase 2: MicroSD (CoCoSDC, via ESP32)
> [!NOTE]
> The MicroSD is connected **directly to the ESP32-C3**, not the RP2350. This allows the ESP32 to serve sectors independently.
*   VCC (3.3V) -> ESP32 3.3V rail | GND -> GND
*   MOSI -> ESP32 **GPIO5**
*   MISO -> ESP32 **GPIO6**
*   SCK (CLK) -> ESP32 **GPIO7**
*   CS -> ESP32 **GPIO10**

### Phase 3: I2S DAC (Orchestra-90 / Speech & Sound)
*   VIN -> **J3 Pin 20 (+5V)** | GND -> GND | SCK -> GND (tie low)
*   BCK -> **J3 Pin 5 (G10)**
*   DIN -> **J3 Pin 7 (G11)**
*   LCK -> **J3 Pin 9 (G12)**
*   R (Right audio) -> R7 (1kΩ) -> RIGHT_RCA (+)
*   L (Left audio) -> R8 (1kΩ) -> LEFT_RCA (+)
*   R7+R8 junction -> R9 (10kΩ Trimpot, wiper) -> GND (Volume control)
*   SND net (C1 10µF coupling) -> J4 Pin 10

### Phase 4: WordPak VGA (SuperSprite FM+)
*   **GREEN** -> **J3 Pin 1 (G8)** -> R4 (470Ω) -> VGA Pin 2
*   **BLUE** -> **J3 Pin 3 (G9)** -> R5 (470Ω) -> VGA Pin 3
*   **RED** -> **J3 Pin 12 (G14)** -> R3 (470Ω) -> VGA Pin 1
*   **VSync** -> **J3 Pin 14 (G16)** -> R1 (100Ω) -> VGA Pin 14
*   **HSync** -> **J3 Pin 16 (G18)** -> R2 (100Ω) -> VGA Pin 13
*   VGA Pins 5, 6, 7, 8, 10 -> GND

### Phase 5: RS-232 (HW-044 Module)
*   TTL_TX -> **J3 Pin 11 (G13)** | TTL_RX -> **J3 Pin 13 (G15)**
*   VCC -> 3.3V | GND -> GND

### Phase 6: Status LED & SDC Button
*   **Status LED**: **J3 Pin 15 (G17)** -> R6 (330Ω) -> LED(+) -> LED(-) -> GND
*   **SDC Button**: **J3 Pin 17 (G19)** -> Switch Pin 2 | Switch Pin 1 -> GND

### Phase 7: ESP32-C3 Super Mini (SPI Coprocessor)
> [!CAUTION]
> These pin assignments are **critical**. Swapping MISO/MOSI or CS/SCK will prevent communication between the RP2350 and ESP32.
*   **CS** : ESP32 **GPIO4** <-> **J4 Pin 7 (G23)**
*   **MISO**: ESP32 **GPIO0** <-> **J4 Pin 9 (G24)**
*   **SCK** : ESP32 **GPIO3** <-> **J4 Pin 15 (G30)**
*   **MOSI**: ESP32 **GPIO1** <-> **J4 Pin 16 (G31)**
*   5V -> J3 Pin 20 (+5V) | GND -> J3 Pin 10 (GND)

---
> [!TIP]
> **First Power-On Check**: Continuity test between 3.3V and GND **before** plugging into the CoCo. Then verify the ESP32 serial output at 115200 baud shows `ESP32-C3 Coprocessor Starting...`

See also: [ecosystem.md](ecosystem.md), [pinmap.md](pinmap.md), [firmware_plan.md](firmware_plan.md).

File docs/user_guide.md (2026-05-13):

# Copico 12-in-1 Master Hat: User Guide
**Date: May 11, 2026**

Welcome to the Copico 12-in-1 Master Hat! This expansion seamlessly turns your Tandy Color Computer into a powerhouse equipped with networking, SD card storage, advanced audio, and high-resolution MSX2+ graphics.

This guide explains how to use the **CoPico X-BIOS BIOS**, the native configuration menu that appears when you boot the CoCo.

---

## 1. The Main Menu

When you power on your CoCo with the Master Hat attached, you are greeted by the **CoPico X-BIOS BIOS Main Menu**. This screen provides an overview of your current hardware configuration and lets you dynamically swap emulated cartridge modes on the fly.

### Dynamic Configuration Toggles
The bottom half of the screen lists the available configuration toggles. Use the keyboard to cycle through the options for each category.

*   `[A]` **Audio**: Cycles between:
    *   **SPEECH/SOUND CARD** (Tandy Speech & Sound Pak emulation)
    *   **ORCHESTRA 90** (High-quality stereo 8-bit DAC emulation)
    *   **REGULAR COCO** (No audio expansion)
*   `[V]` **Video**: Cycles between:
    *   **WORDPAK 2+** (V9958 MSX2+ Graphics)
    *   **SUPER SPRITE FM** (TMS9918 + OPL2 Audio)
    *   **REGULAR COCO** (Native VDG only)
*   `[C]` **Comm**: Cycles between:
    *   **WIMODEM (RS232 PAK)** (WiFi AT-Command Modem)
    *   **RS-232 PAC** (Legacy Serial Communication)
    *   **FUJINET** (Network drive & printing emulator)
    *   **REGULAR COCO** (No communication expansion)
*   `[D]` **Disk**: Cycles between:
    *   **COCOSDC (SD)** (SD Card floppy emulation)
    *   **FUJINET** (Network drive emulation)
    *   **REGULAR COCO** (Native disk controller only)
*   `[R]` **RTC**: Toggles the Real-Time Clock on/off. (When ON, emulates a Disto 4-N-1 MSM5832 RTC, providing time to OS-9/NitrOS-9 automatically upon boot).

*Note: The Comm and Disk options for FujiNet are internally linked. Selecting FujiNet for Disk will automatically switch Comm to FujiNet as well, as they share the same backend architecture.*

### Booting the CoCo
Once you have selected your desired hardware configuration, press `[ENTER]` to lock in the settings and start the CoCo into BASIC or OS-9.

---

## 2. The Advanced Options Menu

If you press `[O]` on the Main Menu, you will be taken to the **Advanced Options** screen. This area provides diagnostic utilities and configuration tools for the RP2350 and ESP32 co-processors.

At the bottom of this screen, you can see real-time status readouts for the **ESP32 Firmware Version** and the **SD Card** capacity.

### Sub-Menus
From the Advanced Options screen, press the corresponding number key to enter a utility:

*   `[1]` **WIFI CONFIGURATION**
    *   Scan for available wireless networks and join them directly from your CoCo.
    *   Use `[S]` to scan again, or `[J]` to join the highlighted network (you will be prompted to enter a password).
*   `[2]` **ALT ROM LOADER**
    *   Browse the `/ROMS` folder on your inserted SD card.
    *   Use `[L]` to load a custom `.ROM` file into the $C000-$DFFF memory space, overriding the default system ROMs. Use `[E]` to eject the loaded ROM.
*   `[3]` **SNIFFER DIAGNOSTICS**
    *   Displays real-time technical metrics about the RP2350 hardware, including the status of the PIO (Programmable I/O) cores and DMA audio channels.
    *   Use `[R]` to reset the internal bus error counters.
*   `[4]` **ESP32 BRIDGE STATUS**
    *   Displays the health of the high-speed SPI link between the RP2350 and the ESP32-C3 network processor.
    *   Use `[P]` to send a ping command to verify connectivity.
*   `[5]` **CLEAR WIFI SETTINGS**
    *   Safely erase your saved WiFi network and password from the ESP32's flash memory.
*   `[6]` **TIME ZONE CONFIGURATION**
    *   Set your local time zone so the Network Time Protocol (NTP) sync provides the correct local time to the RTC.
    *   The top of the screen displays the currently selected time zone.
    *   Use keys `[1]` through `[5]` to select from UTC, EST, CST, MST, or PST. The RTC will instantly update and provide this time to OS-9.

### Returning to the Main Menu
At any time within the Options Menu or its Sub-Menus, press `[X]` to cancel your current action and return to the previous screen.

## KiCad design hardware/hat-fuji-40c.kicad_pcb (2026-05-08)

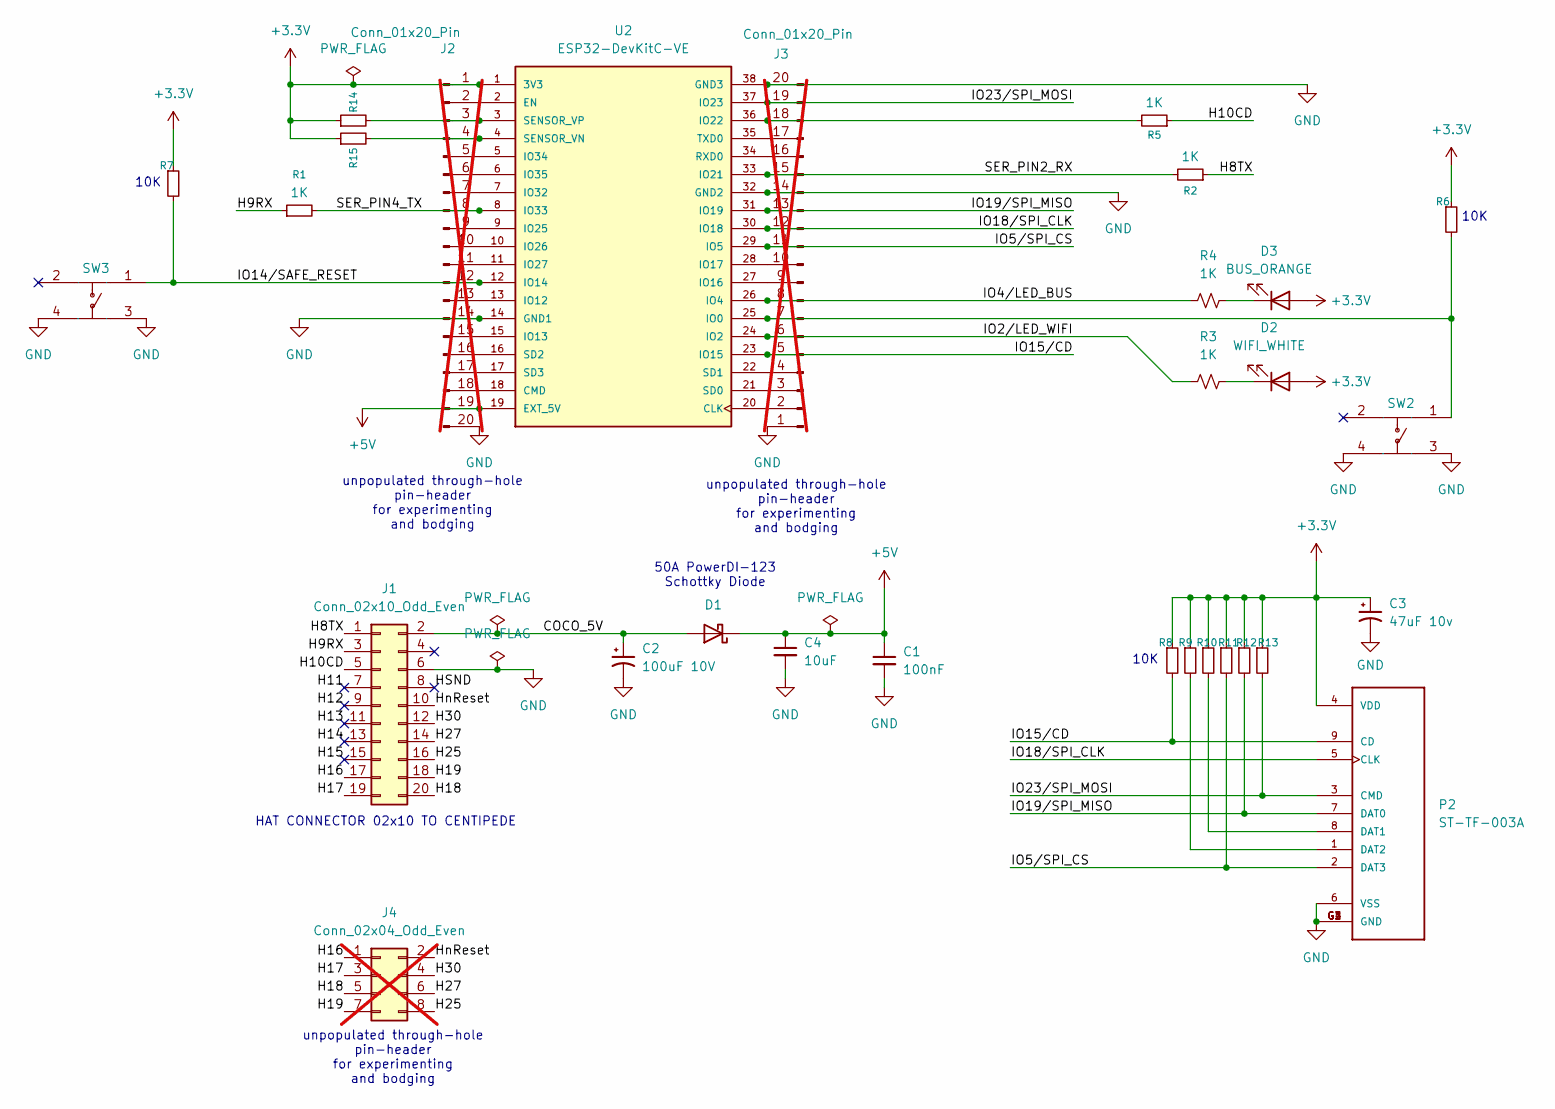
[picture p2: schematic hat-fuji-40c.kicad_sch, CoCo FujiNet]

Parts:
C1: 100nF; C_0402_1005Metric
C2: 100uF 10V; C_1206_3216Metric
C3: 47uF 10v; C_0805_2012Metric
C4: 10uF; C_0603_1608Metric
D1: 50A PowerDI-123 Schottky Diode; D_PowerDI-123
D2: WIFI_WHITE; LED_0603_1608Metric
D3: BUS_ORANGE; LED_0603_1608Metric
J1: Conn_02x10_Odd_Even; PinHeader_2x10_P2.54mm_Vertical_SMD
J2, J3: Conn_01x20_Pin; PinHeader_1x20_P2.54mm_Vertical; not fitted
J4: Conn_02x04_Odd_Even; PinHeader_2x04_P2.54mm_Vertical; not fitted
P2: ST-TF-003A; SUNTECH_ST-TF-003A
R1, R2, R3, R4, R5: 1K; R_0603_1608Metric
R6, R7, R8, R9, R10, R11, R12, R13, R14, R15: R_Small; R_0603_1608Metric
SW2, SW3: K2-1808SN-A4SW-01; KEY-SMD_4P-L4.2-W3.2-P2.20-LS5.1-TL; Manufacturer Part K2-1808SN-A4SW-01; LCSC Part Name 4.2mm*3.25mm
U2: ESP32-DevKitC-VE; MODULE_ESP32-DEVKITC-32U; PARTREV N/A

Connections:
+3.3V: C3.1, D2.2 (A), D3.2 (A), J2.1, P2.4 (VDD), R6.1, R7.1, R8.1, R9.1, R10.1, R11.1, R12.1, R13.1, R14.1, R15.1, U2.1 (3V3)
+5V: C1.1, C4.1, D1.1 (K), J2.19, U2.19 (EXT_5V)
/COCO_5V: C2.1, D1.2 (A), J1.2
/H8TX: J1.1, R2.1
/H9RX: J1.3, R1.1
/H10CD: J1.5, R5.1
/H11: J1.7
/H12: J1.9
/H13: J1.11
/H14: J1.13
/H15: J1.15
/H16: J1.17, J4.1
/H17: J1.19, J4.3
/H18: J1.20, J4.5
/H19: J1.18, J4.7
/H25: J1.16, J4.8
/H27: J1.14, J4.6
/H30: J1.12, J4.4
/HSND: J1.8
/HnReset: J1.10, J4.2
/IO2/LED_WIFI: J3.6, R3.2, U2.24 (IO2)
/IO4/LED_BUS: J3.8, R4.2, U2.26 (IO4)
/IO5/SPI_CS: J3.11, P2.2 (DAT3), R11.2, U2.29 (IO5)
/IO14/SAFE_RESET: J2.12, R7.2, SW3.1, U2.12 (IO14)
/IO15/CD: J3.5, P2.9 (CD), R8.2, U2.23 (IO15)
/IO18/SPI_CLK: J3.12, P2.5 (CLK), U2.30 (IO18)
/IO19/SPI_MISO: J3.13, P2.7 (DAT0), R12.2, U2.31 (IO19)
/IO23/SPI_MOSI: J3.19, P2.3 (CMD), R13.2, U2.37 (IO23)
/SER_PIN2_RX: J3.15, R2.2, U2.33 (IO21)
/SER_PIN4_TX: J2.8, R1.2, U2.8 (IO33)
GND: C1.2, C2.2, C3.2, C4.2, J1.6, J2.14, J2.20, J3.1, J3.14, J3.20, P2.6 (VSS), P2.G1 (GND), P2.G2 (GND), P2.G3 (GND), P2.G4 (GND), SW2.3, SW2.4, SW3.3, SW3.4, U2.14 (GND1), U2.32 (GND2), U2.38 (GND3)
unnamed: D2.1 (K), R3.1
unnamed: D3.1 (K), R4.1
unnamed: J2.2, U2.2 (EN)
unnamed: J2.3, R14.2, U2.3 (SENSOR_VP)
unnamed: J2.4, R15.2, U2.4 (SENSOR_VN)
unnamed: J2.5, U2.5 (IO34)
unnamed: J2.6, U2.6 (IO35)
unnamed: J2.7, U2.7 (IO32)
unnamed: J2.9, U2.9 (IO25)
unnamed: J2.10, U2.10 (IO26)
unnamed: J2.11, U2.11 (IO27)
unnamed: J2.13, U2.13 (IO12)
unnamed: J2.15, U2.15 (IO13)
unnamed: J2.16, U2.16 (SD2)
unnamed: J2.17, U2.17 (SD3)
unnamed: J2.18, U2.18 (CMD)
unnamed: J3.2, U2.20 (CLK)
unnamed: J3.3, U2.21 (SD0)
unnamed: J3.4, U2.22 (SD1)
unnamed: J3.7, R6.2, SW2.1, U2.25 (IO0)
unnamed: J3.9, U2.27 (IO16)
unnamed: J3.10, U2.28 (IO17)
unnamed: J3.16, U2.34 (RXD0)
unnamed: J3.17, U2.35 (TXD0)
unnamed: J3.18, R5.2, U2.36 (IO22)
unnamed: P2.8 (DAT1), R10.2
unnamed: P2.1 (DAT2), R9.2

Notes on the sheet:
50A PowerDI-123 Schottky Diode
10K
unpopulated through-hole pin-header for experimenting and bodging
HAT CONNECTOR 02x10 TO CENTIPEDE

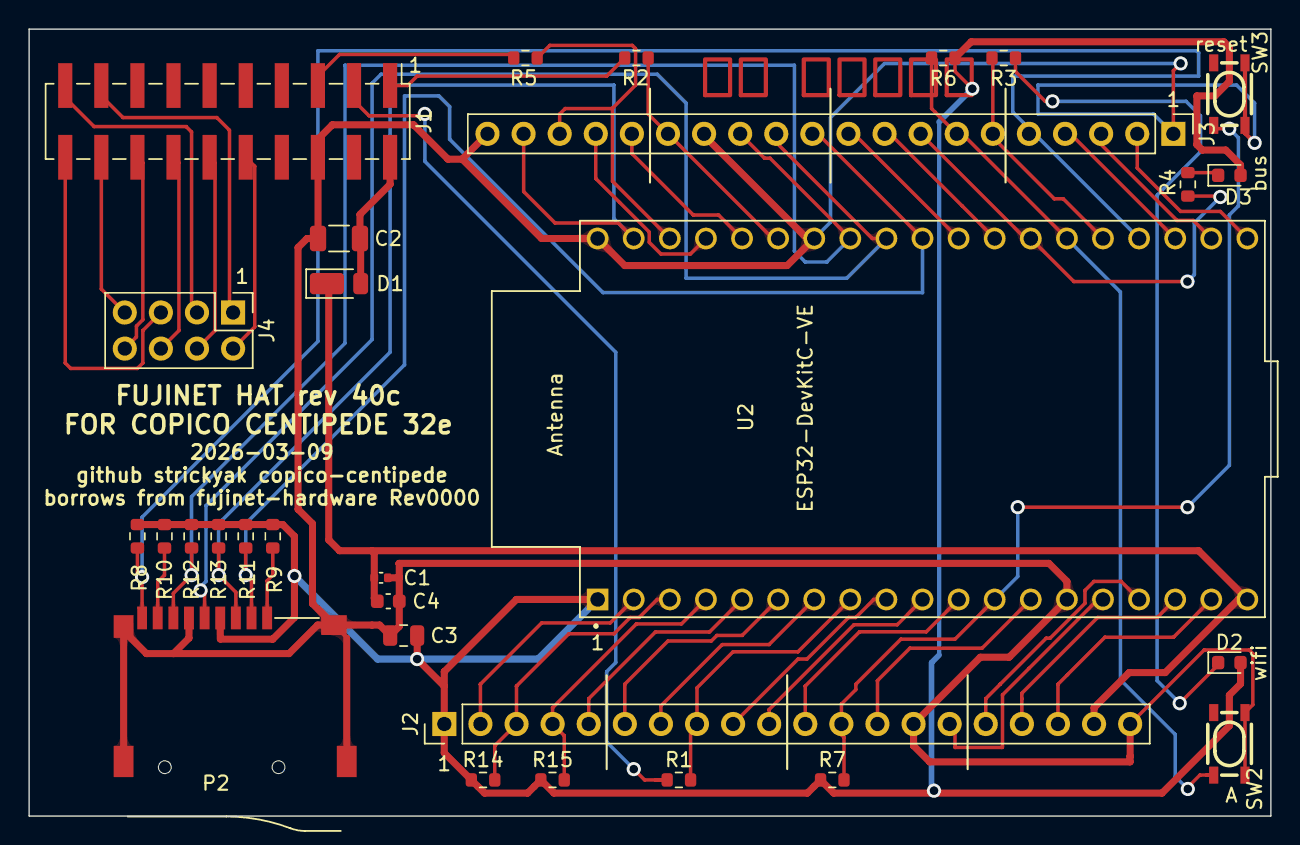
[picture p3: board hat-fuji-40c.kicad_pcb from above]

Board: 2 copper layers, 87.4 x 55.4 mm, 30 parts (0 on the bottom side), 52 nets.

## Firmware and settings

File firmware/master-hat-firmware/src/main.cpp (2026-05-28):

#include <Arduino.h>
#include <EEPROM.h>
#include <I2S.h>
#include "hardware/pio.h"
#include "hardware/structs/sio.h"
#include "hardware/sync.h"
#include "pico/multicore.h"
#include "pico/time.h"
#include "pico/platform.h"
#include "coco_bus.pio.h"
#include "../bios/xbios_rom.h"

#include "pic7040.h"
#include "acia6551.h"
#include "v9958.h"
#include "vga_driver.h"
#include "emulator_mode.h"
#include "boot_menu.h"
#include "cocosdc.h"
#include "spi_stream.h"
#include "esp32_bridge.h"
#include "rtc.h"
#include "io_dispatch.h"
#include "flash_rom_manager.h"
#include "hat_config.h"

#define PIN_BTN_DUAL   19
#define PIN_STATUS_LED 17
#define CENTIPEDE_LED  25

#define I2S_BCK 10
#define I2S_DIN 11
#define I2S_LCK 12

PIO pio = pio0;
uint sm_addr, sm_data, sm_read;

uint8_t dac_left = 128;
uint8_t dac_right = 128;

I2S i2s(OUTPUT);

volatile EmulatorMode current_mode = MODE_BOOT_MENU;
HatConfig active_config;

BootMenu boot_menu;
Rtc rtc;

SerialPIO rs232_serial(13, 15, 256);

Pic7040 pic7040;
Acia6551 acia(&rs232_serial);
SpiStream spi_wimodem_stream;
Acia6551 wimodem(&spi_wimodem_stream);
V9958 v9958;
VgaDriver vga_driver(&v9958);
Cocosdc cocosdc;

uint32_t btn_press_start = 0;
bool btn_is_pressed = false;
bool btn_warning_active = false;
static bool flash_defaults_pending = true;
static bool hardware_init_done = false;
static volatile bool coco_bus_ready = false;
static volatile uint32_t rom_serve_count = 0;
static uint8_t coco_ram[128 * 1024];

static bool usb_host_connected() {
    // Avoid blocking Serial when no monitor is attached (CDC TX can stall).
    return Serial && Serial.dtr();
}

static void boot_log(const char* msg) {
    if (usb_host_connected()) {
        Serial.println(msg);
    }
}

static void stage_blink(uint8_t count) {
    for (uint8_t i = 0; i < count; i++) {
        digitalWrite(CENTIPEDE_LED, HIGH);
        delay(60);
        digitalWrite(CENTIPEDE_LED, LOW);
        delay(60);
    }
    delay(200);
}

void update_orch90_audio();
void enter_boot_menu();
void apply_hat_config(const HatConfig& cfg);

#define PIN_RW      20
#define PIN_E_CLOCK 21
#define PIN_Q       22
#define PIN_CTS     8   // Centipede 32z CTS* (active LOW); shares J3 with hat VGA Green
#define PIN_SCS     9   // Centipede 32z SCS* (active LOW); shares J3 with hat VGA Blue
#define PIN_CART    27  // Centipede 32z CART* (open collector)
#define PIN_SLENB   28  // Centipede 32z SLENB* (open collector)
#define PIN_HALT    29  // Centipede 32z HALT* (open collector)
#define PIN_NMI     30  // Centipede 32z NMI* (open collector)

// J6 schmitt (pins 2-3, 4-5): E/Q inverted at GPIO. Set -DCENTIPEDE_J6_DIRECT=1 for direct E/Q.
#ifndef CENTIPEDE_J6_DIRECT
#define CENTIPEDE_INVERT_EQ 1
#else
#define CENTIPEDE_INVERT_EQ 0
#endif

static bool pio_bus_armed = false;
static bool pio_initialized = false;

static inline void stall_while_e_high() {
    while (gpio_get(PIN_E_CLOCK) == CENTIPEDE_INVERT_EQ) {
        tight_loop_contents();
    }
}

static inline void stall_while_e_low() {
    while (gpio_get(PIN_E_CLOCK) != CENTIPEDE_INVERT_EQ) {
        tight_loop_contents();
    }
}

static inline void stall_while_q_low() {
    while (gpio_get(PIN_Q) != CENTIPEDE_INVERT_EQ) {
        tight_loop_contents();
    }
}

static void disarm_pio_bus() {
    if (!pio_bus_armed) return;
    pio_sm_set_enabled(pio, sm_addr, false);
    pio_sm_set_enabled(pio, sm_data, false);
    pio_sm_set_enabled(pio, sm_read, false);
    gpio_set_dir_in_masked(0xFFu);
    pio_bus_armed = false;
}

static void rearm_pio_bus() {
    if (pio_bus_armed) return;
    pio_sm_set_enabled(pio, sm_read, true);
    pio_enable_sm_mask_in_sync(pio, (1u << sm_addr) | (1u << sm_data));
    pio_bus_armed = true;
}

static bool cart_rom_selected(uint16_t addr) {
    return (addr >= 0xC000 && addr <= 0xDFFF) || addr >= 0xFFFE;
}

static bool in_boot_menu() {
    return current_mode == MODE_BOOT_MENU;
}

static inline bool use_coco_ram(uint16_t abus) {
    return abus < 0x8000u;
}

static inline void init_open_collector_pin(uint pin) {
    gpio_init(pin);
    gpio_set_dir(pin, GPIO_OUT);
    gpio_put(pin, 0);
    gpio_set_dir(pin, GPIO_IN);
    gpio_set_pulls(pin, false, false);
}

static volatile sio_hw_t* const volatile_sio = (volatile sio_hw_t*)sio_hw;

static inline bool vol_gpio_get(uint pin) {
    if (pin < 32u) {
        return (volatile_sio->gpio_in & (1u << pin)) != 0;
    }
    return (volatile_sio->gpio_hi_in & (1u << (pin - 32u))) != 0;
}

// Verbatim Bonobo centipede-watcher foreground body (Engine0 / SmallRam / DoCoco64k).
static void __not_in_flash_func(bonobo_sync_one_cycle)() {
    while (vol_gpio_get(PIN_E_CLOCK) == CENTIPEDE_INVERT_EQ) {
        tight_loop_contents();
    }

    const uint32_t signals = volatile_sio->gpio_in;
    const bool reading = (signals & (1u << PIN_RW)) != 0;
    const uint16_t abus = (uint16_t)(volatile_sio->gpio_hi_in & 0xFFFFu);
    uint8_t dbus = 0;

    constexpr uint32_t NEG_CTS = (1u << PIN_CTS);
    constexpr uint32_t NEG_SCS = (1u << PIN_SCS);
    constexpr uint32_t NEG_SELECTS = NEG_CTS | NEG_SCS;

    if ((signals & NEG_SELECTS) == NEG_SELECTS) {
        if (reading) {
            if (abus >= 0xFF00u) {
                IoReadFunc handler = io_read_table[abus & 0xFFu];
                if (handler) {
                    dbus = handler(abus);
                    gpio_set_dir_out_masked(0xFFu);
                    gpio_put_masked(0xFFu, dbus);
                }
            } else if (use_coco_ram(abus)) {
                dbus = coco_ram[abus];
                gpio_set_dir(PIN_SLENB, GPIO_OUT);
                busy_wait_at_least_cycles(12);
                gpio_set_dir_out_masked(0xFFu);
                gpio_put_masked(0xFFu, dbus);
            }

            while (vol_gpio_get(PIN_E_CLOCK) != CENTIPEDE_INVERT_EQ) {
                tight_loop_contents();
            }
            gpio_set_dir_in_masked(0xFFu);
            gpio_set_dir(PIN_SLENB, GPIO_IN);
        } else {
            while (vol_gpio_get(PIN_Q) != CENTIPEDE_INVERT_EQ) {
                tight_loop_contents();
            }
            dbus = (uint8_t)(volatile_sio->gpio_in & 0xFFu);
            coco_ram[abus] = dbus;
            if (abus >= 0xFF00u) {
                IoWriteFunc handler = io_write_table[abus & 0xFFu];
                if (handler) handler(abus, dbus);
            }
            while (vol_gpio_get(PIN_E_CLOCK) != CENTIPEDE_INVERT_EQ) {
                tight_loop_contents();
            }
        }
    } else if (reading) {
        if ((signals & NEG_CTS) == 0) {
            // Bonobo: disk11_rom[abus & 0x1FFF] — direct table, no function pointer.
            if (abus >= 0xD800u && abus <= 0xD881u && rom_read_handler) {
                dbus = rom_read_handler(abus);
            } else {
                dbus = copico_xbios_bin[abus & 0x1FFFu];
            }
        } else {
            dbus = coco_ram[abus];
            if ((signals & NEG_SCS) == 0 && abus >= 0xFF00u) {
                IoReadFunc handler = io_read_table[abus & 0xFFu];
                if (handler) dbus = handler(abus);
            }
        }

        gpio_set_dir_out_masked(0xFFu);
        gpio_put_masked(0xFFu, dbus);
        while (vol_gpio_get(PIN_E_CLOCK) != CENTIPEDE_INVERT_EQ) {
            tight_loop_contents();
        }
        gpio_set_dir_in_masked(0xFFu);
        rom_serve_count++;
    } else {
        while (vol_gpio_get(PIN_Q) != CENTIPEDE_INVERT_EQ) {
            tight_loop_contents();
        }
        dbus = (uint8_t)(volatile_sio->gpio_in & 0xFFu);
        coco_ram[abus] = dbus;

        if ((signals & NEG_SCS) == 0) {
            if (in_boot_menu() && abus >= 0xFF70u && abus <= 0xFF74u) {
                boot_menu.set_config(abus, dbus);
            } else if (in_boot_menu() && abus == 0xFF76u) {
                boot_menu.set_flash_command(dbus);
            } else if (abus == 0xFF7Fu) {
                if (in_boot_menu() && dbus == 0x55u) {
                    HatConfig cfg;
                    boot_menu.get_config(&cfg);
                    hat_config_save(cfg);
                    apply_hat_config(cfg);
                } else if (dbus == (uint8_t)MODE_BOOT_MENU) {
                    enter_boot_menu();
                }
            } else if (abus >= 0xFF00u) {
                IoWriteFunc handler = io_write_table[abus & 0xFFu];
                if (handler) handler(abus, dbus);
            }
        }

        while (vol_gpio_get(PIN_E_CLOCK) != CENTIPEDE_INVERT_EQ) {
            tight_loop_contents();
        }
    }
}

static void init_centipede_control_pins() {
    // Bonobo centipede-watcher: release open-collector cart control lines.
    gpio_init(PIN_CART);
    gpio_set_dir(PIN_CART, GPIO_OUT);
    gpio_put(PIN_CART, 1);
    init_open_collector_pin(PIN_SLENB);
    init_open_collector_pin(PIN_HALT);
    init_open_collector_pin(PIN_NMI);
}

static void init_coco_bus_gpio() {
    // Bonobo InitializePins: tri-state the entire cart-side GPIO bank first.
    for (uint i = 0; i <= 22; i++) {
        gpio_init(i);
        gpio_set_dir(i, GPIO_IN);
        gpio_set_pulls(i, false, false);
    }
    for (uint i = 32; i <= 47; i++) {
        gpio_init(i);
        gpio_set_dir(i, GPIO_IN);
        gpio_set_pulls(i, false, false);
    }
    init_centipede_control_pins();
}

static void init_hat_gpio() {
    pinMode(PIN_STATUS_LED, OUTPUT);
    digitalWrite(PIN_STATUS_LED, LOW);
    pinMode(PIN_BTN_DUAL, INPUT_PULLUP);

    // Centipede 32z cartridge selects — must stay inputs in X-BIOS mode (not VGA outputs).
    gpio_init(PIN_CTS);
    gpio_init(PIN_SCS);
    gpio_set_dir(PIN_CTS, GPIO_IN);
    gpio_set_dir(PIN_SCS, GPIO_IN);
    gpio_set_pulls(PIN_CTS, false, false);
    gpio_set_pulls(PIN_SCS, false, false);
}

void enter_boot_menu() {
    if (current_mode != MODE_BOOT_MENU) {
        boot_log("[Boot] Entering CoPico X-BIOS menu");
        esp32.send_command(CMD_RESET, nullptr, 0);
    }
    current_mode = MODE_BOOT_MENU;
    rebuild_io_tables_boot_menu();
    boot_menu.init();
    boot_log(rom_read_handler ? "[Boot] X-BIOS ROM handler armed"
                                : "[Boot] ERROR: ROM handler missing");
}

static void init_coco_bus_pio() {
    if (pio_initialized) return;
    init_coco_bus_gpio();

    uint offset_addr = pio_add_program(pio, &coco_sniffer_addr_program);
    uint offset_data = pio_add_program(pio, &coco_sniffer_data_program);
    uint offset_read = pio_add_program(pio, &coco_bus_read_program);

    sm_addr = pio_claim_unused_sm(pio, true);
    sm_data = pio_claim_unused_sm(pio, true);
    sm_read = pio_claim_unused_sm(pio, true);

    pio_sm_config c_addr = coco_sniffer_addr_program_get_default_config(offset_addr);
    sm_config_set_in_pins(&c_addr, 32);
    pio_sm_init(pio, sm_addr, offset_addr, &c_addr);

    pio_sm_config c_data = coco_sniffer_data_program_get_default_config(offset_data);
    sm_config_set_in_pins(&c_data, 0);
    pio_sm_init(pio, sm_data, offset_data, &c_data);

    pio_sm_config c_read = coco_bus_read_program_get_default_config(offset_read);
    sm_config_set_out_pins(&c_read, 0, 8);
    sm_config_set_set_pins(&c_read, 0, 8);
    sm_config_set_out_shift(&c_read, true, false, 8);
    sm_config_set_clkdiv(&c_read, 1.0f);
    for (int i = 0; i < 8; i++) pio_gpio_init(pio, i);
    for (int i = 32; i < 48; i++) pio_gpio_init(pio, i);
    pio_sm_set_consecutive_pindirs(pio, sm_read, 0, 8, false);
    pio_sm_init(pio, sm_read, offset_read, &c_read);
    pio_sm_set_enabled(pio, sm_read, true);

    pio_enable_sm_mask_in_sync(pio, (1u << sm_addr) | (1u << sm_data));
    pio_initialized = true;
    pio_bus_armed = true;
}

void apply_hat_config(const HatConfig& cfg) {
    HatConfig c = cfg;
    hat_config_apply_constraints(c);

    if (current_mode != MODE_BOOT_MENU) {
        esp32.send_command(CMD_RESET, nullptr, 0);
    }

    active_config = c;
    current_mode = MODE_HAT_ACTIVE;

    rebuild_io_tables_config(c);
    hat_config_log(c, active_layers);

    if (active_layers.internal_rom) {
        Serial.println("[Config] Internal ROM — hat tri-stated");
        return;
    }

    i2s.setBCLK(I2S_BCK);
    i2s.setDATA(I2S_DIN);
    i2s.setBitsPerSample(16);
    i2s.begin(44100);
    spi_wimodem_stream.begin();
    rtc.init();

    if (active_layers.cocosdc) cocosdc.init();
    if (active_layers.wordpak) vga_driver.init();
    if (active_layers.rs232) acia.init(false);
    if (active_layers.wimodem) wimodem.init(true);
    if (active_layers.fujinet) {
        if (!flash_rom.load_rom_to_buffer(SLOT_FUJINET,
                                          io_dispatch_fujinet_rom_buffer(),
                                          nullptr, nullptr)) {
            Serial.println("[Config] FujiNet ROM load failed");
        }
    }
}

static void init_hat_hardware() {
    init_hat_gpio();
    Serial.begin(115200);
    boot_log("[Boot] CoPico RP2350 starting (RP2350B / Centipede 32z)");
    boot_log("[Boot] init: EEPROM");
    EEPROM.begin(512);
    stage_blink(5);
    boot_log("[Boot] X-BIOS ready — slow blink = alive");
    hardware_init_done = true;
}

// Earliest hook Arduino calls on core0 — tri-state cart GPIO before USB/Serial init.
void initVariant() {
    init_coco_bus_gpio();
}

void setup() {
    // CoCo bus is already live on core1 (setup1). Core0 only handles UI / hat init.
    pinMode(CENTIPEDE_LED, OUTPUT);
    digitalWrite(CENTIPEDE_LED, LOW);

#ifdef PICO_DEFAULT_LED_PIN
    pinMode(PICO_DEFAULT_LED_PIN, OUTPUT);
#endif
}

void loop() {
    if (!hardware_init_done) {
        init_hat_hardware();
        stage_blink(6);
        return;
    }

    if (flash_defaults_pending) {
        // X-BIOS serves from embedded ROM; skip heavy flash writes at boot.
        if (flash_rom.is_slot_empty(SLOT_COCOSDC)) {
            flash_rom.status_flags |= FLASH_STATUS_SDC_MISSING;
        }
        flash_defaults_pending = false;
    }

    if (digitalRead(PIN_BTN_DUAL) == LOW) {
        if (!btn_is_pressed) {
            btn_is_pressed = true;
            btn_press_start = millis();
            btn_warning_active = false;
        } else {
            uint32_t hold_time = millis() - btn_press_start;

            if (hold_time >= 5000) {
                digitalWrite(PIN_STATUS_LED, LOW);
                btn_is_pressed = false;
                Serial.println("System Reset Triggered -> Returning to Boot Menu");
                enter_boot_menu();
            } else if (hold_time >= 3000) {
                digitalWrite(PIN_STATUS_LED, (millis() / 100) % 2);
                btn_warning_active = true;
            }
        }
    } else {
        if (btn_is_pressed) {
            uint32_t hold_time = millis() - btn_press_start;
            btn_is_pressed = false;

            if (btn_warning_active) {
                digitalWrite(PIN_STATUS_LED, LOW);
                btn_warning_active = false;
            } else if (hold_time < 1000 && active_layers.cocosdc) {
                Serial.println("Disk Swap Triggered");
                esp32.sdc_swap();
            }
        }
    }

    if (in_boot_menu()) {
        boot_menu.service_flash_command();
        HatConfig pending;
        if (boot_menu.consume_pending_config_apply(&pending)) {
            hat_config_save(pending);
            apply_hat_config(pending);
        }

        digitalWrite(PIN_STATUS_LED, (millis() / 500) % 2);
#ifdef PICO_DEFAULT_LED_PIN
        digitalWrite(PICO_DEFAULT_LED_PIN, (millis() / 500) % 2);
#endif
        digitalWrite(CENTIPEDE_LED, (millis() / 500) % 2);
        delay(10);
        return;
    }

    if (active_layers.speech) {
        pic7040.tick();
        int16_t sample_l = 0, sample_r = 0;
        pic7040.generate_audio(&sample_l, &sample_r);
        i2s.write(sample_l);
        i2s.write(sample_r);
    }

    if (active_layers.wordpak) {
        vga_driver.tick();
    }

    if (active_layers.cocosdc) {
        cocosdc.tick();
    }

    if (active_layers.wimodem) {
        spi_wimodem_stream.tick();
    }

    if (!active_layers.speech && !active_layers.wordpak &&
        !active_layers.cocosdc && !active_layers.wimodem) {
        delay(1);
    }
}

void setup1() {
    // First instruction on core1: serve the CoCo bus (do not wait for core0 setup()).
    init_coco_bus_gpio();
    enter_boot_menu();
    coco_bus_ready = true;
    multicore_lockout_victim_init();

    uint32_t ints = save_and_disable_interrupts();
    while (in_boot_menu()) {
        bonobo_sync_one_cycle();
    }
    restore_interrupts(ints);
}

#define BUS_RESPOND(byte) pio_sm_put_blocking(pio, sm_read, (uint32_t)(byte))

void loop1() {
    if (in_boot_menu()) return;

    if (!pio_initialized) {
        init_coco_bus_pio();
    }
    rearm_pio_bus();

    if (pio_sm_is_rx_fifo_empty(pio, sm_addr)) return;

    uint32_t addr = pio_sm_get(pio, sm_addr);
    bool is_read = gpio_get(PIN_RW);

    if (is_read) {
        if (!pio_sm_is_rx_fifo_empty(pio, sm_data)) {
            (void)pio_sm_get(pio, sm_data);
        }
    } else {
        if (pio_sm_is_rx_fifo_empty(pio, sm_data)) return;
    }

    uint32_t data = is_read ? 0 : pio_sm_get(pio, sm_data);
    bool cts_active = (gpio_get(PIN_CTS) == 0);
    bool scs_active = (gpio_get(PIN_SCS) == 0);

    if (is_read) {
        if (cart_rom_selected((uint16_t)addr) && rom_read_handler && cts_active) {
            BUS_RESPOND(rom_read_handler((uint16_t)addr));
            rom_serve_count++;
            return;
        }

        if (addr >= 0xFF00) {
            if (!scs_active) return;
            IoReadFunc handler = io_read_table[addr & 0xFF];
            if (handler) {
                BUS_RESPOND(handler(addr));
            }
        }
    } else {
        if (in_boot_menu() && scs_active && addr >= 0xFF70 && addr <= 0xFF74) {
            boot_menu.set_config(addr, (uint8_t)data);
            return;
        }

        if (in_boot_menu() && scs_active && addr == 0xFF76) {
            boot_menu.set_flash_command((uint8_t)data);
            return;
        }

        if (scs_active && addr == 0xFF7F) {
            if (in_boot_menu() && data == 0x55) {
                HatConfig cfg;
                boot_menu.get_config(&cfg);
                hat_config_save(cfg);
                apply_hat_config(cfg);
            } else if (data == (uint8_t)MODE_BOOT_MENU) {
                enter_boot_menu();
            }
            return;
        }

        if (addr >= 0xFF00) {
            if (!scs_active) return;
            IoWriteFunc handler = io_write_table[addr & 0xFF];
            if (handler) {
                handler(addr, (uint8_t)data);
            }
        }
    }
}

void update_orch90_audio() {
    int16_t sample_l = ((int16_t)dac_left - 128) << 8;
    int16_t sample_r = ((int16_t)dac_right - 128) << 8;
    i2s.write(sample_l);
    i2s.write(sample_r);
}

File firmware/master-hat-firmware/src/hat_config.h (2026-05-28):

#pragma once

#include <Arduino.h>

// Toggle values — must match xbios.asm VAR_* / REG_* encoding
#define XBIOS_AUDIO_SPEECH   0
#define XBIOS_AUDIO_ORCH90   1
#define XBIOS_AUDIO_OFF      2

#define XBIOS_VIDEO_WORDPAK  0
#define XBIOS_VIDEO_SUPER    1
#define XBIOS_VIDEO_OFF      2

#define XBIOS_DISK_SDC       0
#define XBIOS_DISK_FUJINET   1
#define XBIOS_DISK_OFF       2
#define XBIOS_DISK_INTERNAL  3

#define XBIOS_COMM_WIMODEM   0
#define XBIOS_COMM_RS232     1
#define XBIOS_COMM_FUJINET   2
#define XBIOS_COMM_OFF       3

#define XBIOS_RTC_OFF        0
#define XBIOS_RTC_ON         1

#define HAT_EEPROM_MAGIC     0xC0
#define HAT_EEPROM_ADDR_MAGIC 0
#define HAT_EEPROM_ADDR_AUDIO 1
#define HAT_EEPROM_ADDR_VIDEO 2
#define HAT_EEPROM_ADDR_DISK  3
#define HAT_EEPROM_ADDR_COMM  4
#define HAT_EEPROM_ADDR_RTC   5

struct HatConfig {
    uint8_t audio = XBIOS_AUDIO_OFF;
    uint8_t video = XBIOS_VIDEO_OFF;
    uint8_t disk  = XBIOS_DISK_SDC;
    uint8_t comm  = XBIOS_COMM_OFF;
    uint8_t rtc   = XBIOS_RTC_OFF;
};

struct HatLayerFlags {
    bool boot_menu    = false;
    bool speech       = false;
    bool orch90       = false;
    bool wordpak      = false;
    bool cocosdc      = false;
    bool fujinet      = false;
    bool rs232        = false;
    bool wimodem      = false;
    bool internal_rom = false;
};

void hat_config_apply_constraints(HatConfig& cfg);
HatLayerFlags hat_config_to_layers(const HatConfig& cfg);
bool hat_config_is_valid(const HatConfig& cfg);
bool hat_config_load(HatConfig* out);
void hat_config_save(const HatConfig& cfg);
void hat_config_log(const HatConfig& cfg, const HatLayerFlags& layers);

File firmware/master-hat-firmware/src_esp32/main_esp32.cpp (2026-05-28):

#include <Arduino.h>
#include <driver/spi_slave.h>
#include <driver/gpio.h>
#include "spi_protocol.h"
#include "ModemEngine.h"
#include "SdFat.h"
#include "sdios.h"
#include <time.h>
#include <WiFi.h>

// Define ESP32-C3 pins connected to RP2350 SPI (Hardware Layout Phase 10)
#define ESP_SPI_MISO 0
#define ESP_SPI_MOSI 1
#define ESP_SPI_SCK  3
#define ESP_SPI_CS   4

#define SPI_HOST SPI2_HOST // FSPI on ESP32-C3

// Define SD Card Pins (Software SPI because SPI2 is used by Slave)
#define SD_MOSI 5
#define SD_MISO 6
#define SD_SCK  7
#define SD_CS   10

SoftSpiDriver<SD_MISO, SD_MOSI, SD_SCK> softSpi;
SdFat sd;
FsFile drives[2];

// Buffers for SPI DMA (Must be DMA-capable memory)
WORD_ALIGNED_ATTR SpiMasterPacket rx_packet;
WORD_ALIGNED_ATTR SpiSlavePacket tx_packet;

// Internal FIFOs to act as our Stream buffers for the ModemEngine
#define ESP_FIFO_SIZE 1024
uint8_t modem_rx_fifo[ESP_FIFO_SIZE]; // Data coming FROM RP2350
volatile uint16_t modem_rx_head = 0;
volatile uint16_t modem_rx_tail = 0;

uint8_t modem_tx_fifo[ESP_FIFO_SIZE]; // Data going TO RP2350
volatile uint16_t modem_tx_head = 0;
volatile uint16_t modem_tx_tail = 0;

uint32_t last_sys_info_time = 0;
char current_tz_name[32] = "UTC (GMT)";

// ROM fetch buffer for CoPico X-BIOS flash utility (max 16KB file)
static uint8_t rom_fetch_buf[16384];
static uint16_t rom_fetch_size = 0;
const char* tz_strings[] = {
    // North America
    "NST3:30NDT,M3.2.0,M11.1.0",
    "AST4ADT,M3.2.0,M11.1.0",
    "EST5EDT,M3.2.0,M11.1.0",
    "CST6CDT,M3.2.0,M11.1.0",
    "MST7MDT,M3.2.0,M11.1.0",
    "PST8PDT,M3.2.0,M11.1.0",
    // Europe/World
    "UTC0",
    "WET0WEST,M3.5.0/1,M10.5.0",
    "CET-1CEST,M3.5.0,M10.5.0",
    "EET-2EEST,M3.5.0/3,M10.5.0/4",
    "MSK-3",
    "GST-4",
    // Asia/Oceania
    "IST-5:30",
    "CST-8",
    "JST-9",
    "AWST-8",
    "ACST-9:30ACDT,M10.1.0,M4.1.0",
    "AEST-10AEDT,M10.1.0,M4.1.0"
};
const char* tz_names[] = {
    // North America
    "UTC-3:30 (St. John's)",
    "UTC-4 (Halifax)",
    "UTC-5 (Toronto)",
    "UTC-6 (Winnipeg)",
    "UTC-7 (Calgary)",
    "UTC-8 (Vancouver)",
    // Europe/World
    "UTC (GMT)",
    "UTC+0 (London)",
    "UTC+1 (Paris)",
    "UTC+2 (Athens)",
    "UTC+3 (Moscow)",
    "UTC+4 (Dubai)",
    // Asia/Oceania
    "UTC+5:30 (New Delhi)",
    "UTC+8 (Beijing)",
    "UTC+9 (Tokyo)",
    "UTC+8 (Perth)",
    "UTC+9:30 (Adelaide)",
    "UTC+10 (Sydney)"
};

void spi_slave_init() {
    // Configuration for the SPI bus
    spi_bus_config_t buscfg = {
        .mosi_io_num = ESP_SPI_MOSI,
        .miso_io_num = ESP_SPI_MISO,
        .sclk_io_num = ESP_SPI_SCK,
        .quadwp_io_num = -1,
        .quadhd_io_num = -1,
        .max_transfer_sz = 256,
    };

    // Configuration for the SPI slave interface
    spi_slave_interface_config_t slvcfg = {
        .spics_io_num = ESP_SPI_CS,
        .flags = 0,
        .queue_size = 3,
        .mode = 0,
        .post_setup_cb = NULL,
        .post_trans_cb = NULL
    };

    // Initialize SPI slave interface
    esp_err_t ret = spi_slave_initialize(SPI_HOST, &buscfg, &slvcfg, SPI_DMA_CH_AUTO);
    assert(ret == ESP_OK);
}

void process_spi_transaction() {
    spi_slave_transaction_t t;
    memset(&t, 0, sizeof(t));

    // We assume the RP2350 will always send exactly sizeof(SpiMasterPacket)
    t.length = sizeof(SpiMasterPacket) * 8; 
    t.tx_buffer = &tx_packet;
    t.rx_buffer = &rx_packet;

    // Wait for the master to initiate the transaction
    esp_err_t ret = spi_slave_transmit(SPI_HOST, &t, portMAX_DELAY);
    if (ret == ESP_OK) {
        // Validate RX Packet from RP2350
        if (rx_packet.sync == SPI_SYNC_BYTE) {
            uint8_t expected_checksum = calc_checksum((const uint8_t*)&rx_packet, sizeof(rx_packet) - 1);
            if (expected_checksum == rx_packet.checksum) {
                
                // --- HANDLE INCOMING COMMANDS ---
                if (rx_packet.command == CMD_TX_DATA && rx_packet.length <= SPI_PAYLOAD_SIZE) {
                    for (int i = 0; i < rx_packet.length; i++) {
                        uint16_t next_head = (modem_rx_head + 1) % ESP_FIFO_SIZE;
                        if (next_head != modem_rx_tail) {
                            modem_rx_fifo[modem_rx_head] = rx_packet.payload[i];
                            modem_rx_head = next_head;
                        }
                    }
                } 
                else if (rx_packet.command == CMD_SDC_READ) {
                    uint8_t drive_id = rx_packet.payload[0];
                    uint32_t lsn = ((uint32_t)rx_packet.payload[1] << 16) | 
                                   ((uint32_t)rx_packet.payload[2] << 8) | 
                                   rx_packet.payload[3];
                                   
                    if (drive_id < 2 && drives[drive_id]) {
                        drives[drive_id].seekSet(lsn * 256);
                        int bytes_read = drives[drive_id].read(tx_packet.payload, 256);
                        if (bytes_read < 256) memset(tx_packet.payload + bytes_read, 0, 256 - bytes_read);
                        
                        tx_packet.status = STATUS_SDC_SECTOR;
                        tx_packet.length = 256;
                    } else {
                        tx_packet.status = STATUS_SDC_ACK; // Will send error code
                        tx_packet.payload[0] = 0x80; // Error
                        tx_packet.length = 1;
                    }
                }
                else if (rx_packet.command == CMD_SDC_WRITE) {
                    uint8_t drive_id = rx_packet.payload[0];
                    uint32_t lsn = ((uint32_t)rx_packet.payload[1] << 16) | 
                                   ((uint32_t)rx_packet.payload[2] << 8) | 
                                   rx_packet.payload[3];
                                   
                    if (drive_id < 2 && drives[drive_id]) {
                        drives[drive_id].seekSet(lsn * 256);
                        drives[drive_id].write(&rx_packet.payload[4], 256);
                        drives[drive_id].sync();
                        
                        tx_packet.status = STATUS_SDC_ACK;
                        tx_packet.payload[0] = 0x00; // Success
                        tx_packet.length = 1;
                    } else {
                        tx_packet.status = STATUS_SDC_ACK;
                        tx_packet.payload[0] = 0x80; // Error
                        tx_packet.length = 1;
                    }
                }
                else if (rx_packet.command == CMD_SDC_MOUNT) {
                    uint8_t drive_id = rx_packet.payload[0];
                    char filename[250];
                    memcpy(filename, &rx_packet.payload[1], rx_packet.length - 1);
                    filename[rx_packet.length - 1] = '\0';
                    
                    if (drive_id < 2) {
                        if (drives[drive_id]) drives[drive_id].close();
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

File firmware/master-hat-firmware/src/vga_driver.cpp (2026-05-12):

#include "vga_driver.h"
#include "vga_pio.pio.h"
#include "hardware/clocks.h"
#include "hardware/irq.h"

// ==========================================================
// VGA Pin Definitions — Verified against PCB Netlist
// Centipede 32z Hat-Fuji-40C schematic, dated 2026-04-19
// SuperSprite FM+ / WordPac 2+ VGA Module (KH-HDR15P-F3.08)
// J3 Header Mapping:
//   J3 Pin 1  -> VGA_GREEN_G8  -> R4 (470R) -> VGA Pin 2
//   J3 Pin 3  -> VGA_BLUE_G9   -> R5 (470R) -> VGA Pin 3
//   J3 Pin 12 -> VGA_RED_G14   -> R3 (470R) -> VGA Pin 1
//   J3 Pin 14 -> VGA_VSync_G16 -> R1 (100R) -> VGA Pin 14
//   J3 Pin 16 -> VGA_HSync_G18 -> R2 (100R) -> VGA Pin 13
// ==========================================================
#define PIN_GREEN 8
#define PIN_BLUE  9
#define PIN_RED   14
#define PIN_VSYNC 16
#define PIN_HSYNC 18

// Global instance pointer for the static DMA ISR callback
VgaDriver* g_vga_driver_instance = nullptr;

VgaDriver::VgaDriver(V9958* vdp) : _vdp(vdp) {
    _next_render_line = 0;
    _active_buffer_idx = 0;
    _scanlines_completed = 0;
    _dma_read_ptr = nullptr;
}

void VgaDriver::init() {
    build_color_table();
    g_vga_driver_instance = this;

    // Init pins
    gpio_init(PIN_RED);
    gpio_init(PIN_GREEN);
    gpio_init(PIN_BLUE);
    gpio_init(PIN_HSYNC);
    gpio_init(PIN_VSYNC);

    gpio_set_dir(PIN_RED, GPIO_OUT);
    gpio_set_dir(PIN_GREEN, GPIO_OUT);
    gpio_set_dir(PIN_BLUE, GPIO_OUT);
    gpio_set_dir(PIN_HSYNC, GPIO_OUT);
    gpio_set_dir(PIN_VSYNC, GPIO_OUT);

    _pio = pio1; // PIO1 to avoid conflict with bus sniffer on PIO0

    init_pio();
    init_dma();
}

void VgaDriver::build_color_table() {
    // We map 3-bit color (0-7) to a 16-bit PIO instruction
    // PIO instruction format for: set pins, <data> side <side_data>
    // Opcode: 111 (SET) | S (Sideset) | DDDD (Delay=7) | 000 (Destination) | 000 GB (Data)
    // SIDESET base = 14 (RED), SET base = 8 (GREEN, BLUE)
    // Green is bit 0 of SET, Blue is bit 1 of SET.
    // Red is bit 0 of SIDESET.
    
    // Base instruction: 111_0_0111_000_00000 = 0xE700
    for (int i = 0; i < 8; i++) {
        uint16_t instr = 0xE700;
        
        bool r = (i & 0x4) ? 1 : 0;
        bool g = (i & 0x2) ? 1 : 0;
        bool b = (i & 0x1) ? 1 : 0;
        
        if (r) instr |= (1 << 12); // Sideset bit 0 is at bit 12
        if (g) instr |= (1 << 0);  // Green is bit 0 of data
        if (b) instr |= (1 << 1);  // Blue is bit 1 of data
        
        _color_instruction[i] = instr;
    }
}

void VgaDriver::init_pio() {
    // 1. Add programs to PIO
    uint offset_hsync = pio_add_program(_pio, &vga_hsync_program);
    uint offset_vsync = pio_add_program(_pio, &vga_vsync_program);
    uint offset_rgb   = pio_add_program(_pio, &vga_rgb_program);

    _sm_hsync = pio_claim_unused_sm(_pio, true);
    _sm_vsync = pio_claim_unused_sm(_pio, true);
    _sm_rgb   = pio_claim_unused_sm(_pio, true);

    // 2. Configure HSYNC SM
    pio_sm_config c_hsync = vga_hsync_program_get_default_config(offset_hsync);
    sm_config_set_set_pins(&c_hsync, PIN_HSYNC, 1);
    pio_gpio_init(_pio, PIN_HSYNC);
    pio_sm_set_consecutive_pindirs(_pio, _sm_hsync, PIN_HSYNC, 1, true);
    sm_config_set_clkdiv(&c_hsync, 10.0f); // 250MHz / 10 = 25MHz
    pio_sm_init(_pio, _sm_hsync, offset_hsync, &c_hsync);

    // 3. Configure VSYNC SM
    pio_sm_config c_vsync = vga_vsync_program_get_default_config(offset_vsync);
    sm_config_set_set_pins(&c_vsync, PIN_VSYNC, 1);
    sm_config_set_sideset_pins(&c_vsync, PIN_VSYNC);
    pio_gpio_init(_pio, PIN_VSYNC);
    pio_sm_set_consecutive_pindirs(_pio, _sm_vsync, PIN_VSYNC, 1, true);
    sm_config_set_clkdiv(&c_vsync, 10.0f); // 25MHz
    pio_sm_init(_pio, _sm_vsync, offset_vsync, &c_vsync);
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

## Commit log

2026-05-08 Initial commit: Organized hardware, documentation, and references for 12-in-1 Master Hat
    [hat-fuji-40c.kicad_pcb, hat-fuji-40c.kicad_sch]
2026-05-09 Phase 4 Complete: V9958 Emulation and VGA Driver integrated. Ready for Phase 5 Boot Menu.
2026-05-11 Complete Phase 8-12: Architecture Refactor & ESP32 SPI Bridge
2026-05-11 Phase 6 Complete: BIOS UI fully implemented, SPI pins fixed
    [esp32_bridge.cpp]
2026-05-12 Update Phase 7 prompt with ACIA status and ESP32 project details
2026-05-12 Phase 7: Wireless Suite - ESP32 Coprocessor scaffolding, Custom WiModem Engine, and SPI Arbitration
2026-05-12 Phase 8 Fortification: Pin Audit - Correct SPI G23/24/30/31, update all docs to match verified PCB netlist
    [esp32_bridge.cpp, main.cpp, vga_driver.cpp]
2026-05-12 Phase 8 Fortification: PIO read-response SM - cut bus latency from ~500ns to ~154ns, safe for 6309 @ 1.78MHz
2026-05-12 Phase 8 Fortification: Hybrid Fast-Map I/O dispatch - 256-entry table replaces if/else chain, ~120ns latency, safe for GIME-X @ 2.86MHz
    [main.cpp]
2026-05-12 Phase 8 Fortification: SPI deadlock insurance - tiered timeouts, retry limits, diagnostic logging, fixed spi_stream pins
    [esp32_bridge.cpp, spi_stream.cpp]
2026-05-12 Phase 8 Fortification: VGA jitter elimination - DMA interrupt-driven double buffer, no blocking loops in tick()
    [vga_driver.cpp]
2026-05-13 Phase 9: Flash ROM Bank Architecture - factory slots for Chameleon/FujiNet/RS232/DiskBASIC, SDC-DOS auto-install from SD, G19 panic boot, status flag
2026-05-13 Step 5: Add MODE_INTERNAL_ROM, MODE_FUJINET, MODE_MAX to EmulatorMode enum; wire tri-state and FujiNet flash-load into switch_mode()
2026-05-24 Add project docs, workspace setup, and portable BIOS build.
    Document the verified hat schematic and GPIO pin map, multi-root workspace,
    and Cursor ignore rules for obsolete KiCad. Fix doc links, remove wrong
    build guide wiring, resolve lwasm via sibling lwtools, and regenerate X-BIOS ROM.
2026-05-28 Archive Arduino RP2350 bring-up and X-BIOS updates before 10in1_Multi_Hat fork.
    Preserves boot menu, io_dispatch, hat_config, and test harness work for
    reference; hardware-validated CoCo bus path moved to Bonobo copico-watcher.
